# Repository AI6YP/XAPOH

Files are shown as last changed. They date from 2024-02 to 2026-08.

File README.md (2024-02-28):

<p align="right"></p>

# Спутник Плутона -- ХАРОН

Предварительные каскады для Analog Devices ADALM-PLUTO SDR.

https://wiki.analog.com/university/tools/pluto

* Передняя панель управления и индикации
* Задняя панель с разъёмами
* Основная плата

## Панели v1.0.0

### Вид спереди / сзади




Исходные файлы для печатной платы:
* hw/front.svg
* hw/back.svg

Для получения KiCAD проекта используйте Inkscape + svg2shenzhen

https://github.com/badgeek/svg2shenzhen

Для получения GERBER файлов используйте KiCAD

Для надписей использован шрифт B612:

https://fonts.google.com/specimen/B612

### Перечень элементов

| Поз.<br> обозна- <br>чение | Наименование | Кол. | Примечание |
|-|-|-|-|
| D1 | VS1838B | 1 | |
| R1 | Переменный резистор 10К | 1 | |
| ИН1 | Индикатор 2" TFT ST7789V | 1 | |
| SB1 SB2 | Кнопка 6x6x5 | 2 | |
| Р1 - Р9 | SMA -> IPEX | 9 | |
| Р10 | DB9 | 1 | |

### Передняя панель

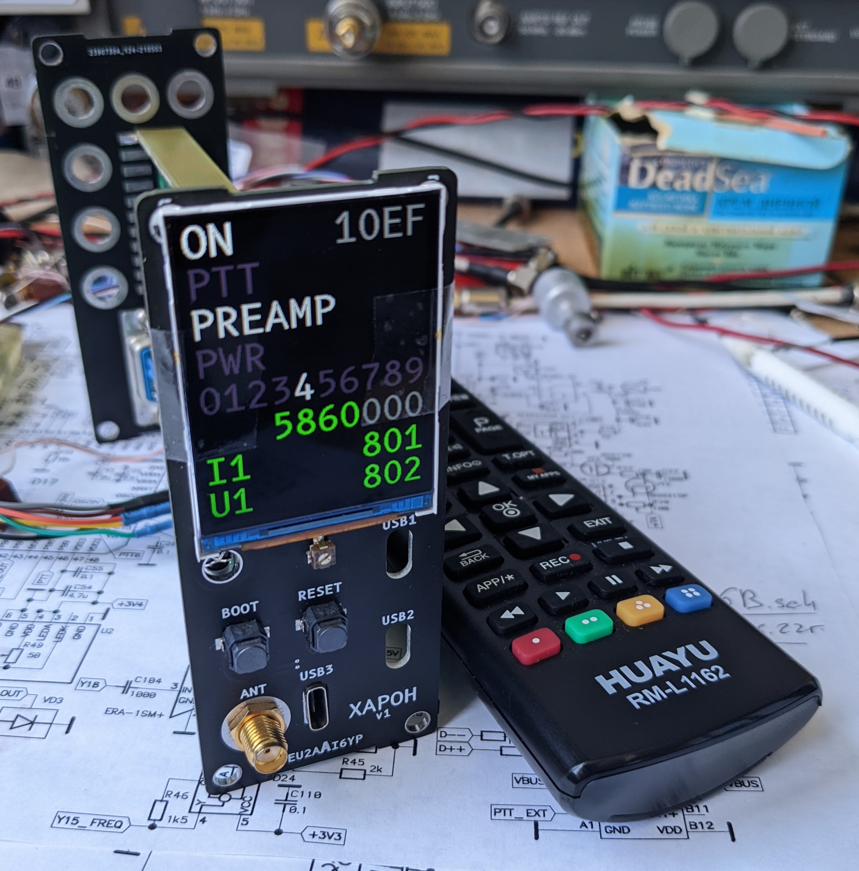
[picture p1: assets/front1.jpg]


### Вид спереди в корпусе

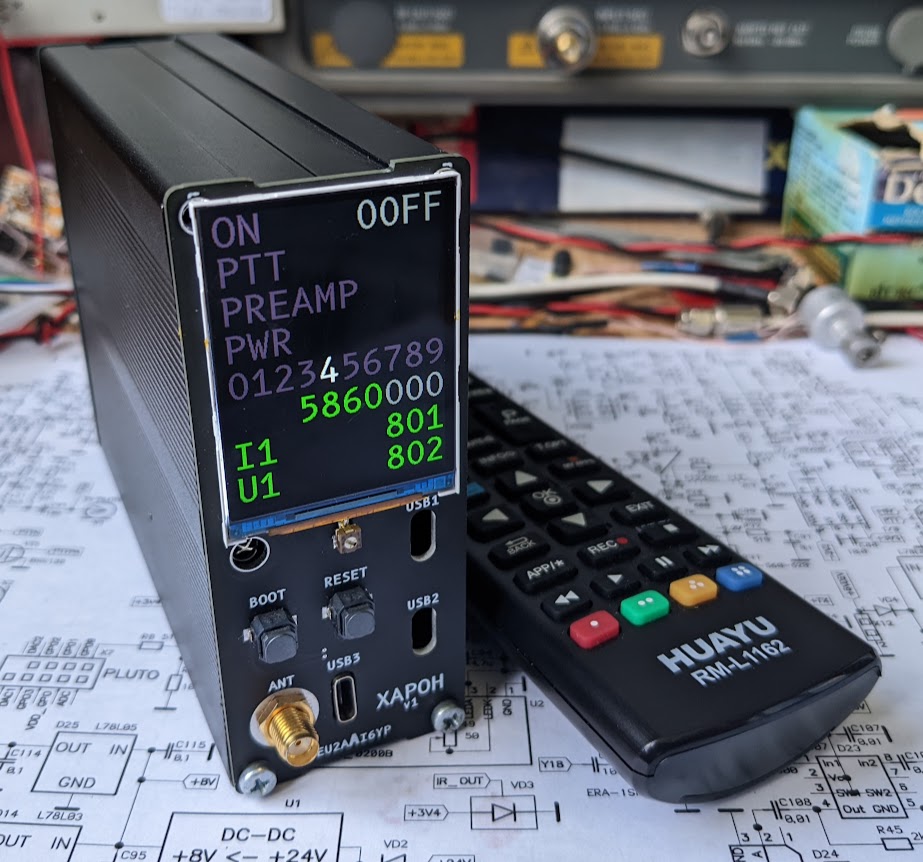
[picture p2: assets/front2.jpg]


### Задняя панель

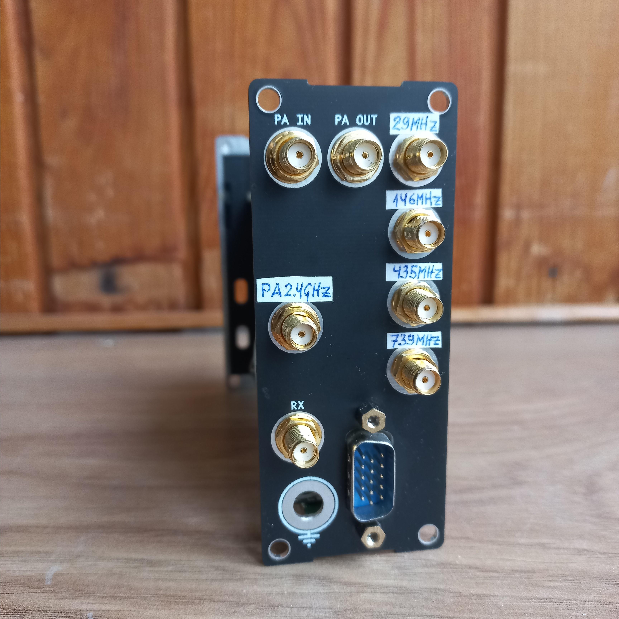
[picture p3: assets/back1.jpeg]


## Основная плата v1.0.0

### Схема антенной секции

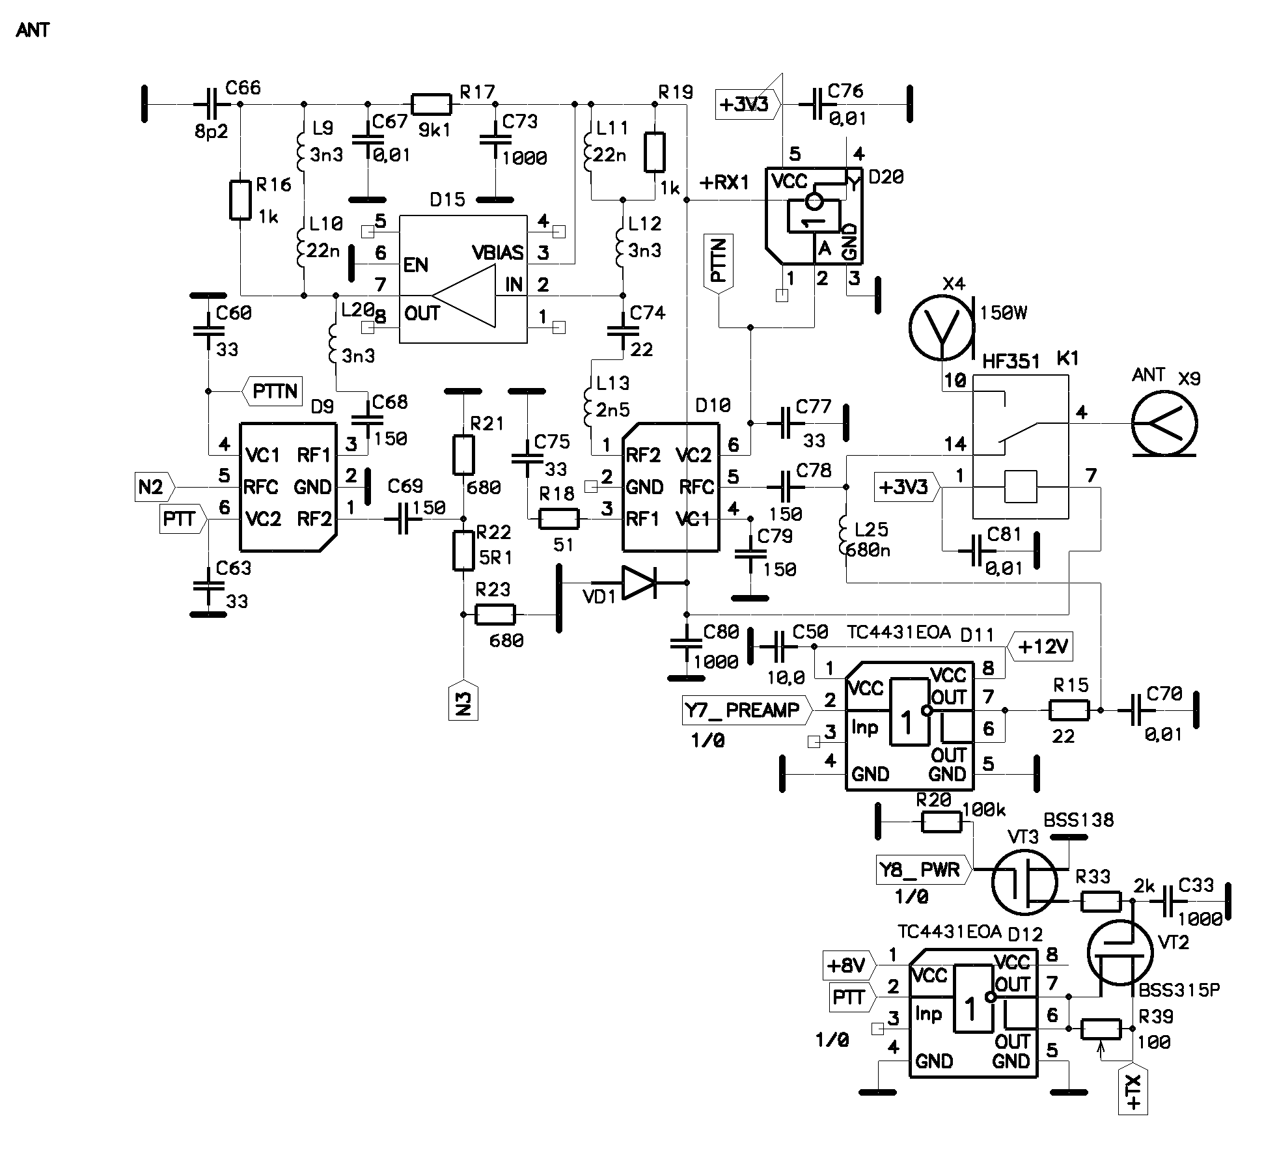
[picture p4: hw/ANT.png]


### Схема процессорной секции

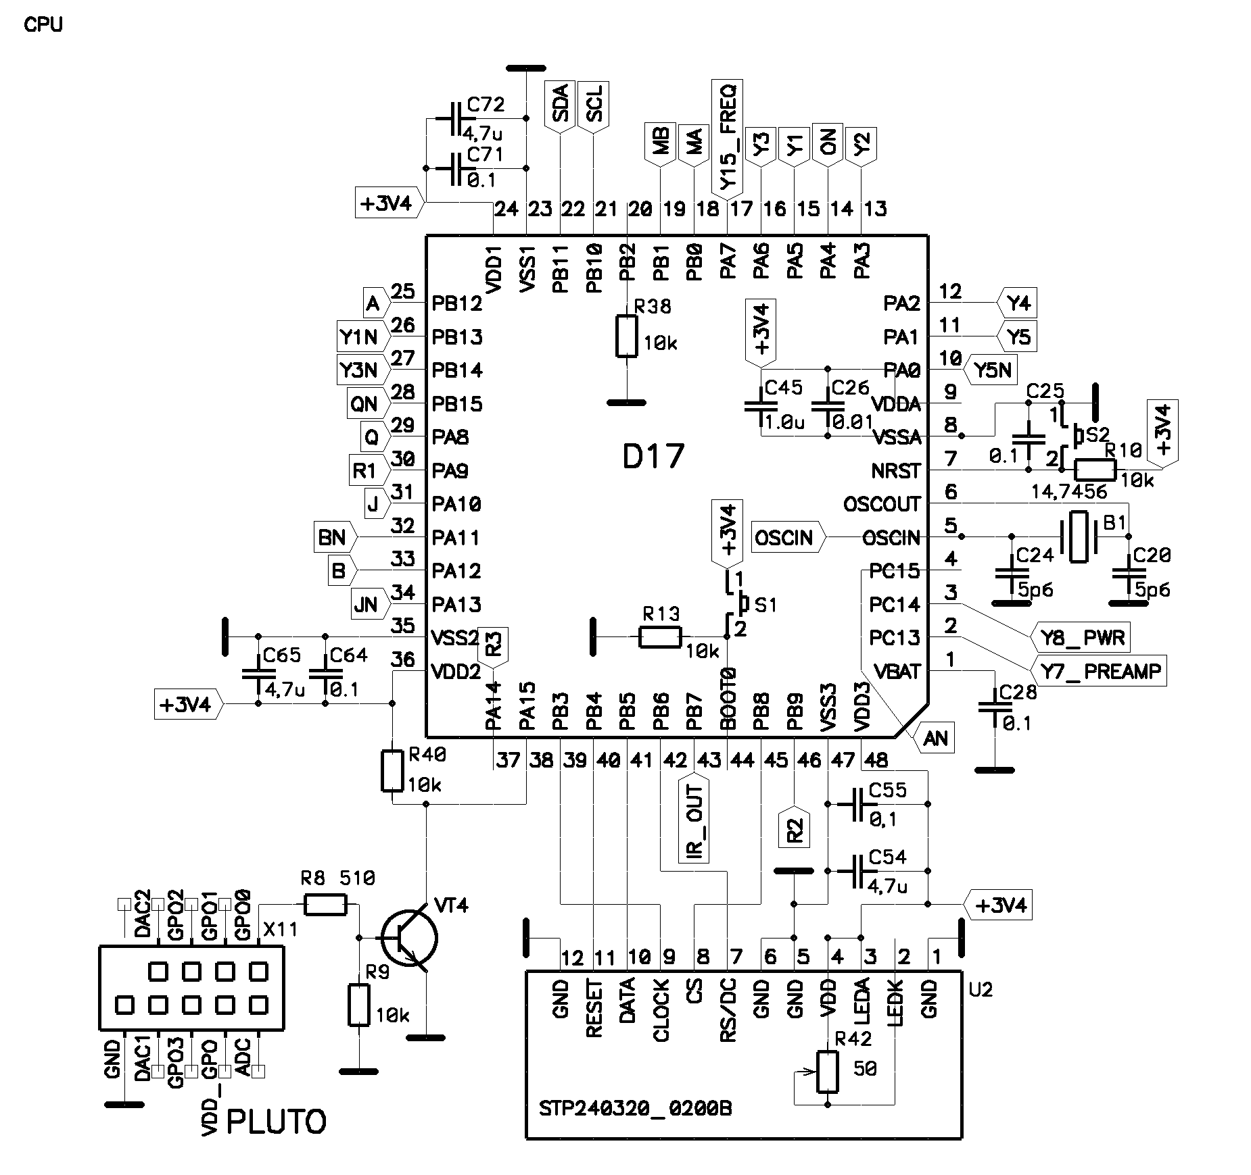
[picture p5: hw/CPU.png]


### Схема секции источник питания

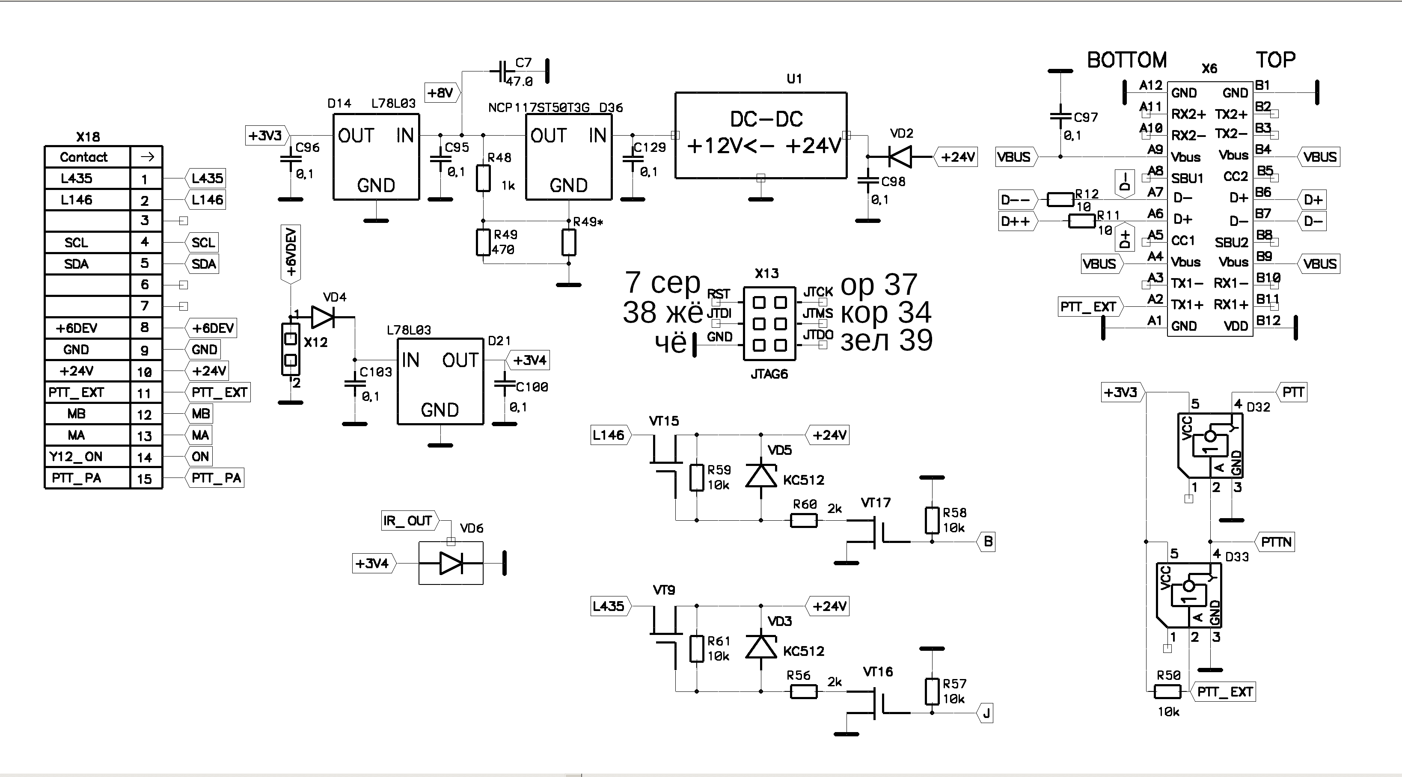
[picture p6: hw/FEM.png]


### Схема секции фильтров

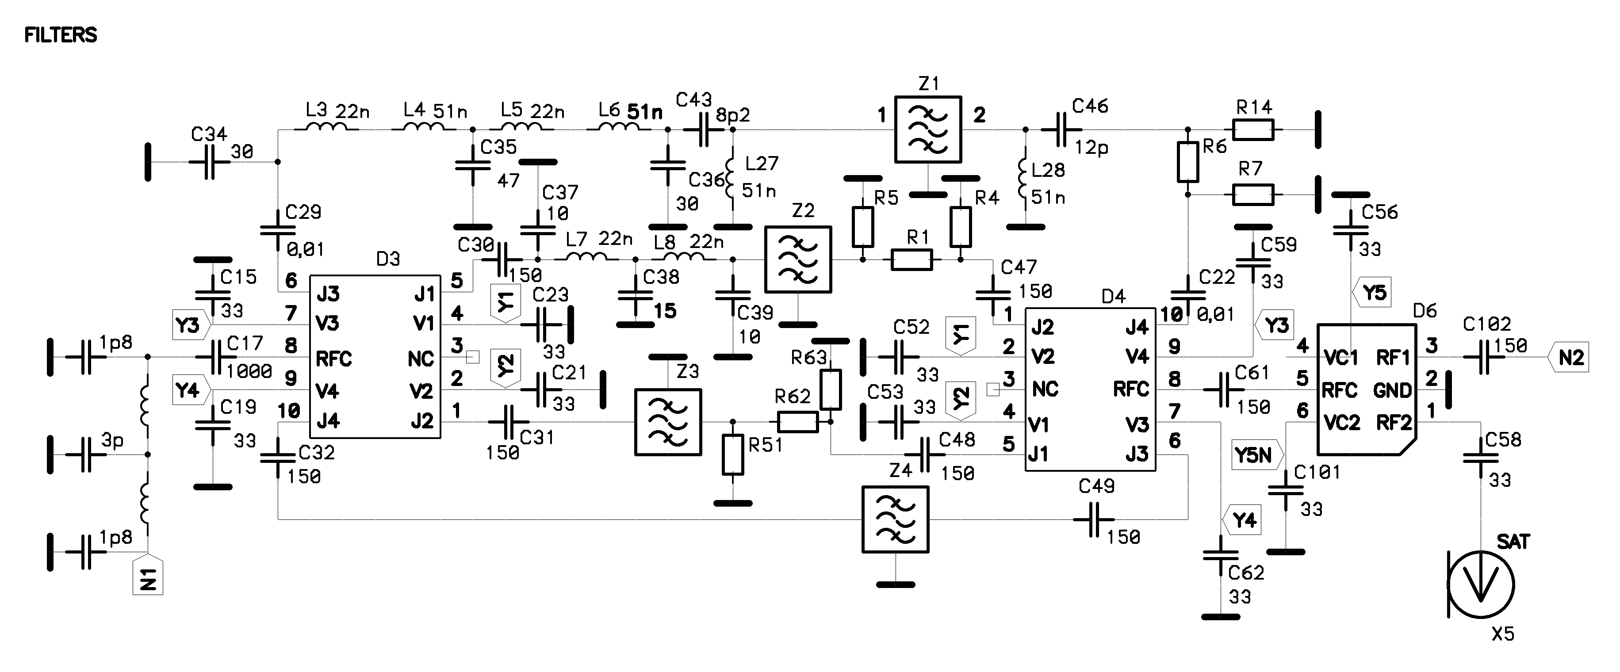
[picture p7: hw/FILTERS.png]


### Схема секции усилителя

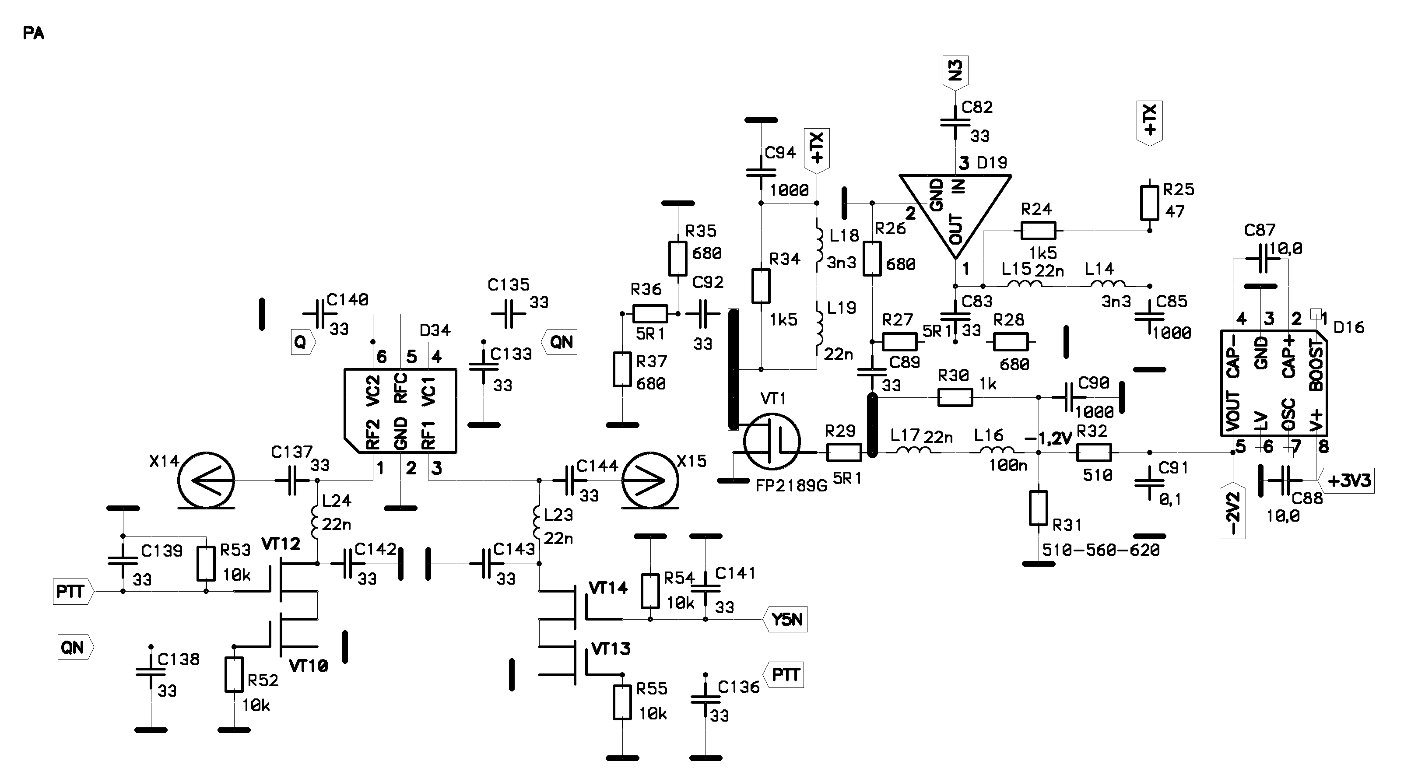
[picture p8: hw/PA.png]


### Схема секции приёмника

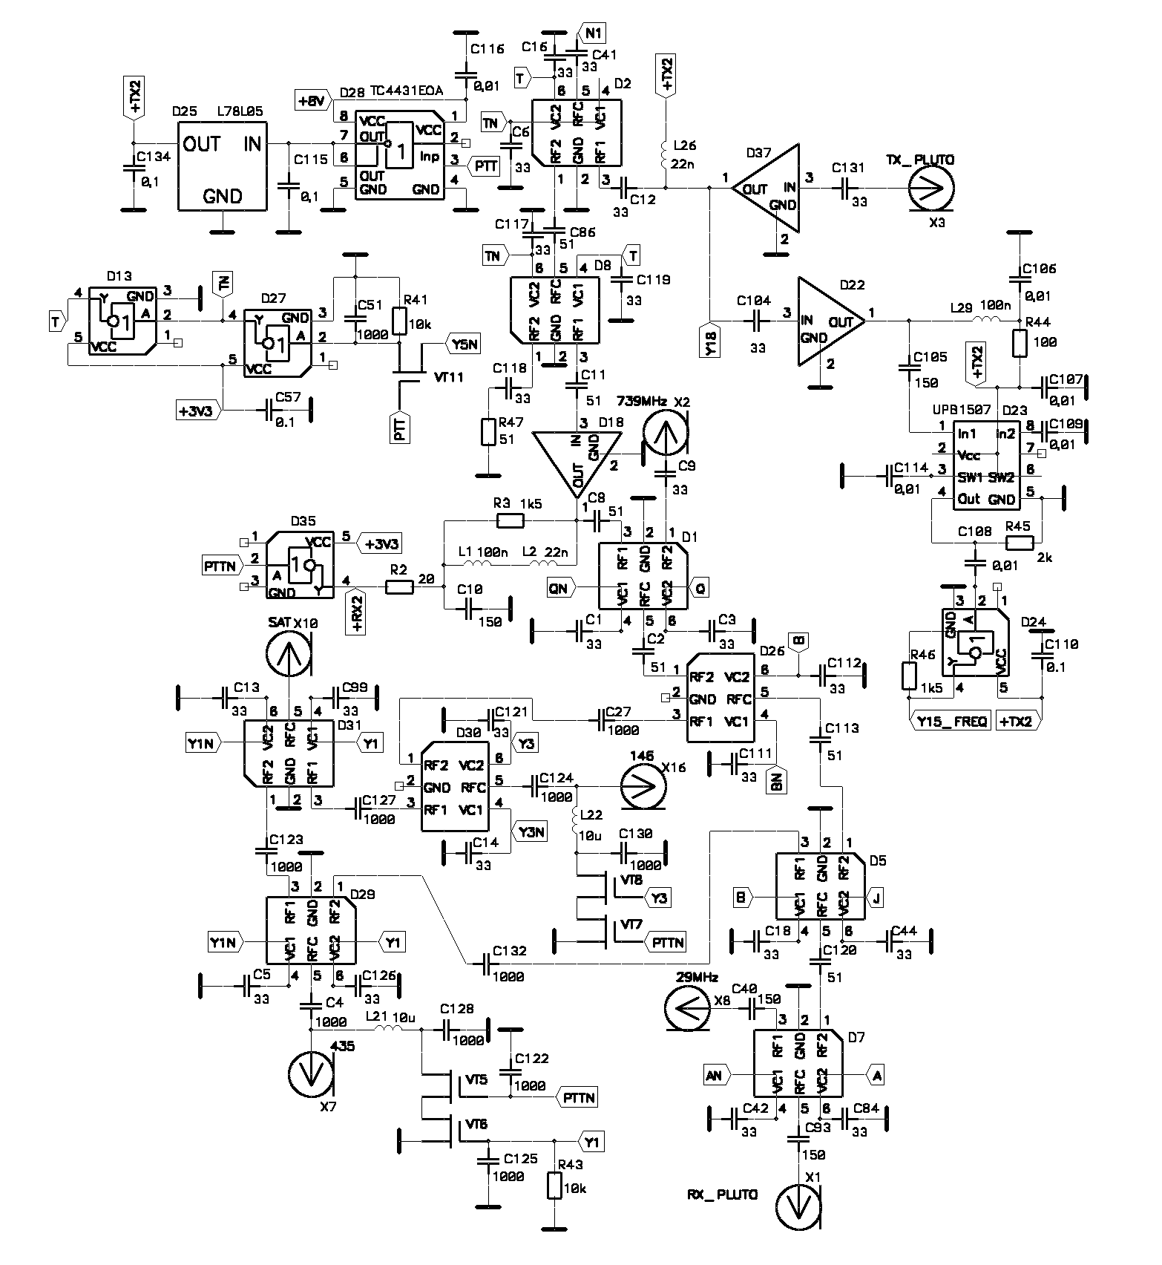
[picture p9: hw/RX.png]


### Топология платы лицевая сторона

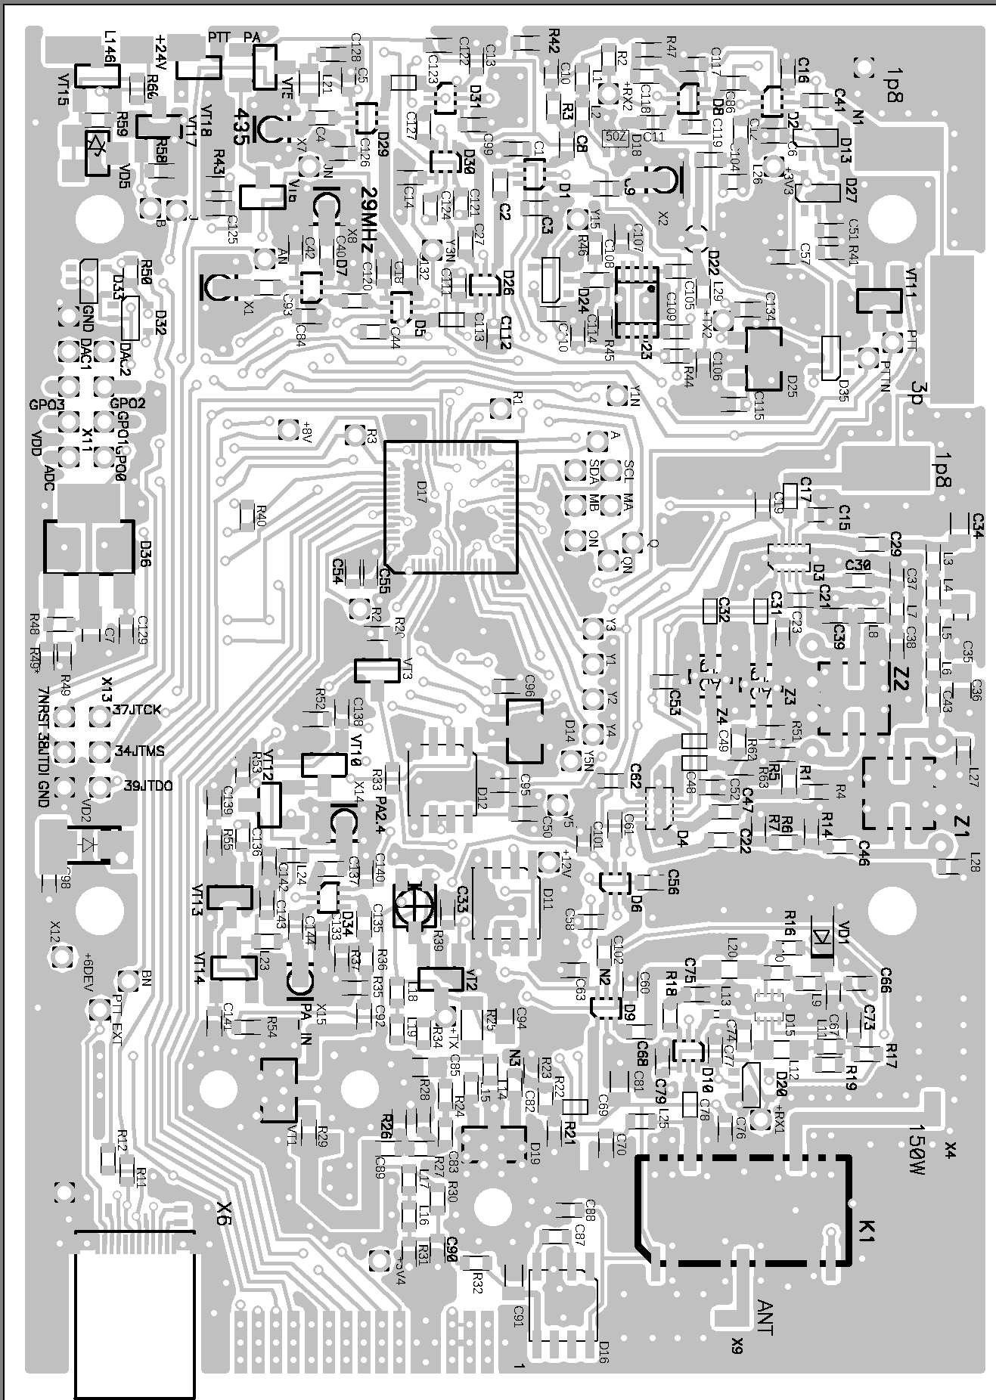
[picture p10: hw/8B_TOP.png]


### Топология платы обратная сторонв

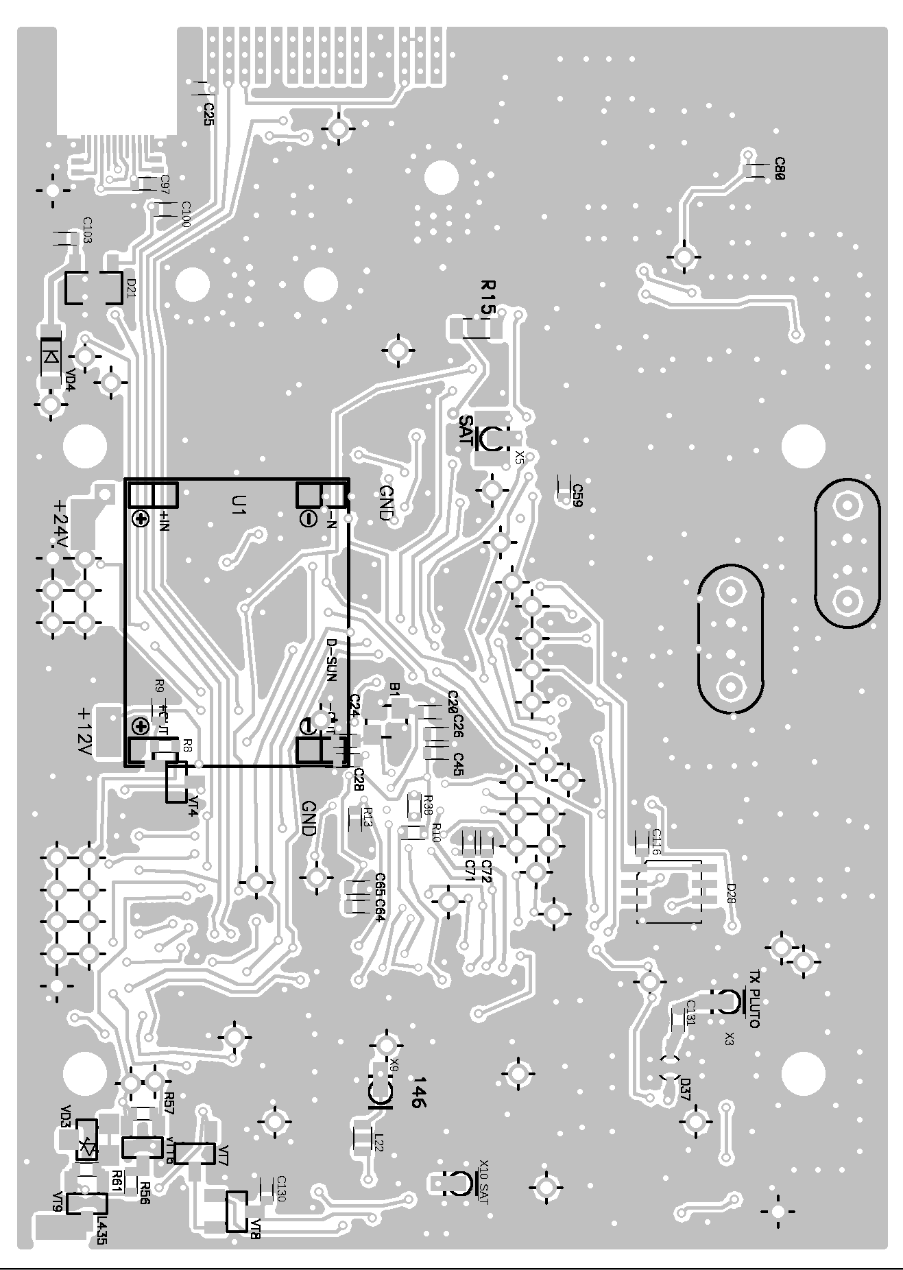
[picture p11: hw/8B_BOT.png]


## Корпус

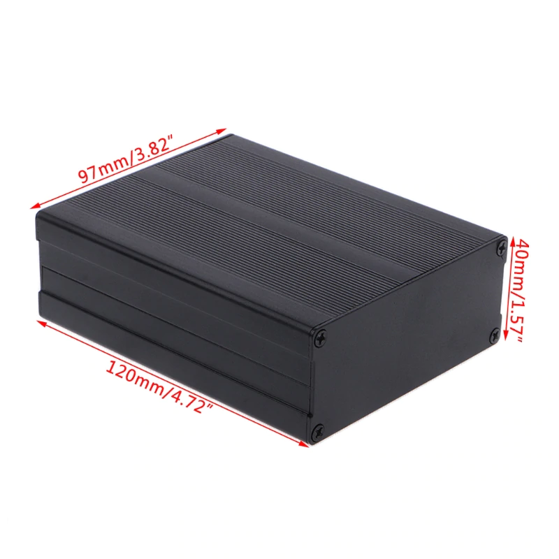
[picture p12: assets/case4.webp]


## Индикатор

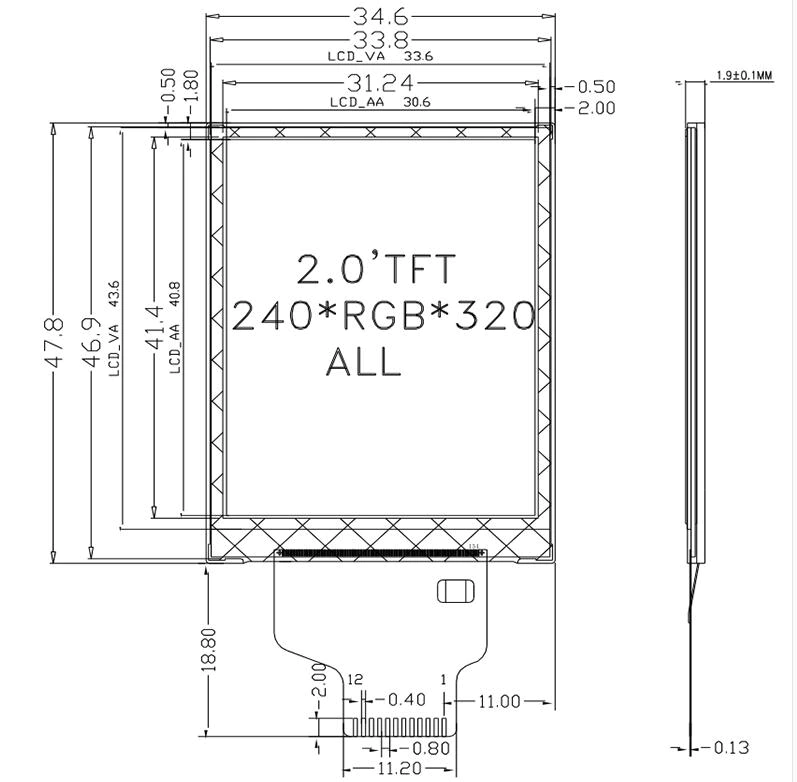
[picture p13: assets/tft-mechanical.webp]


## Фото устройства

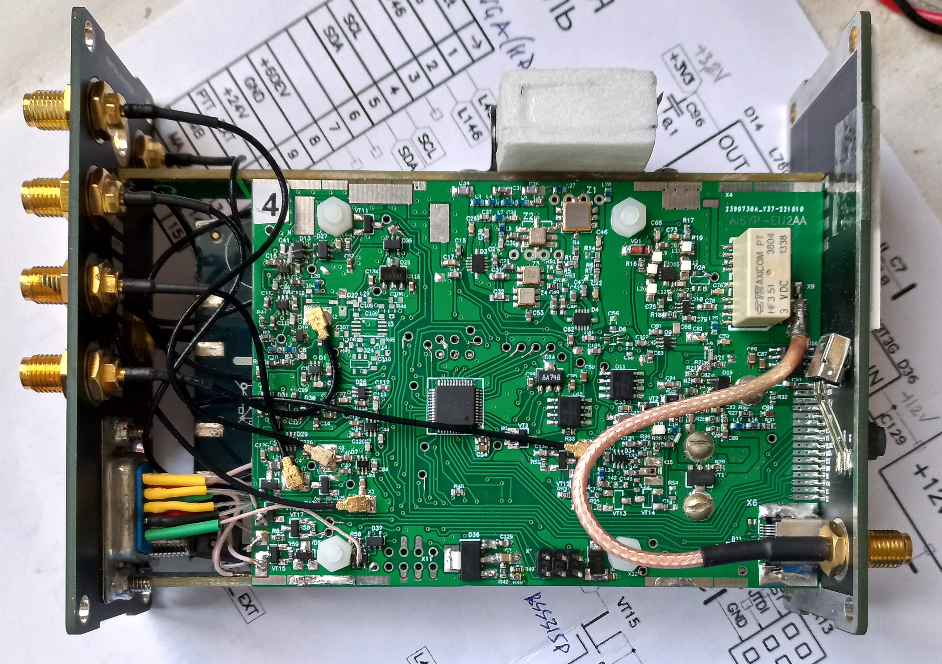
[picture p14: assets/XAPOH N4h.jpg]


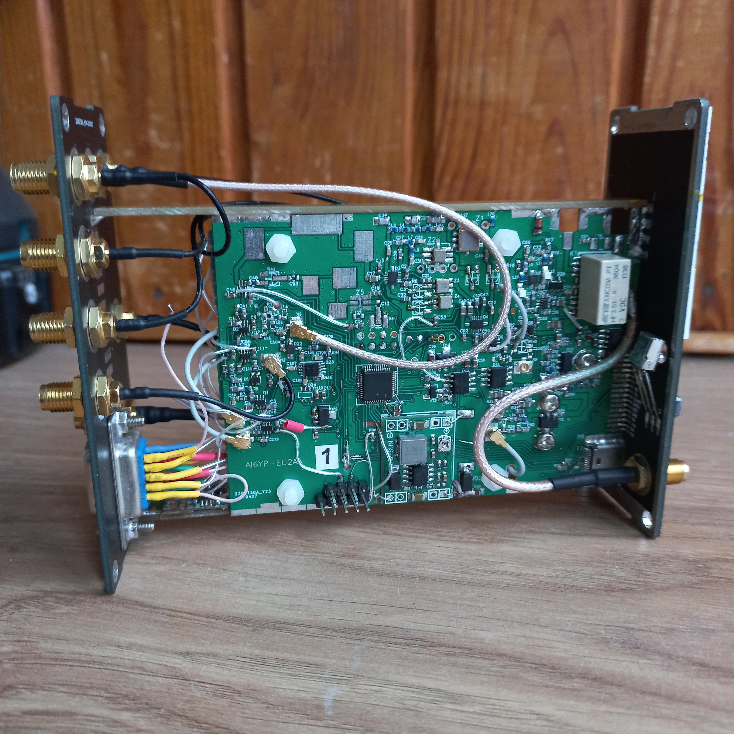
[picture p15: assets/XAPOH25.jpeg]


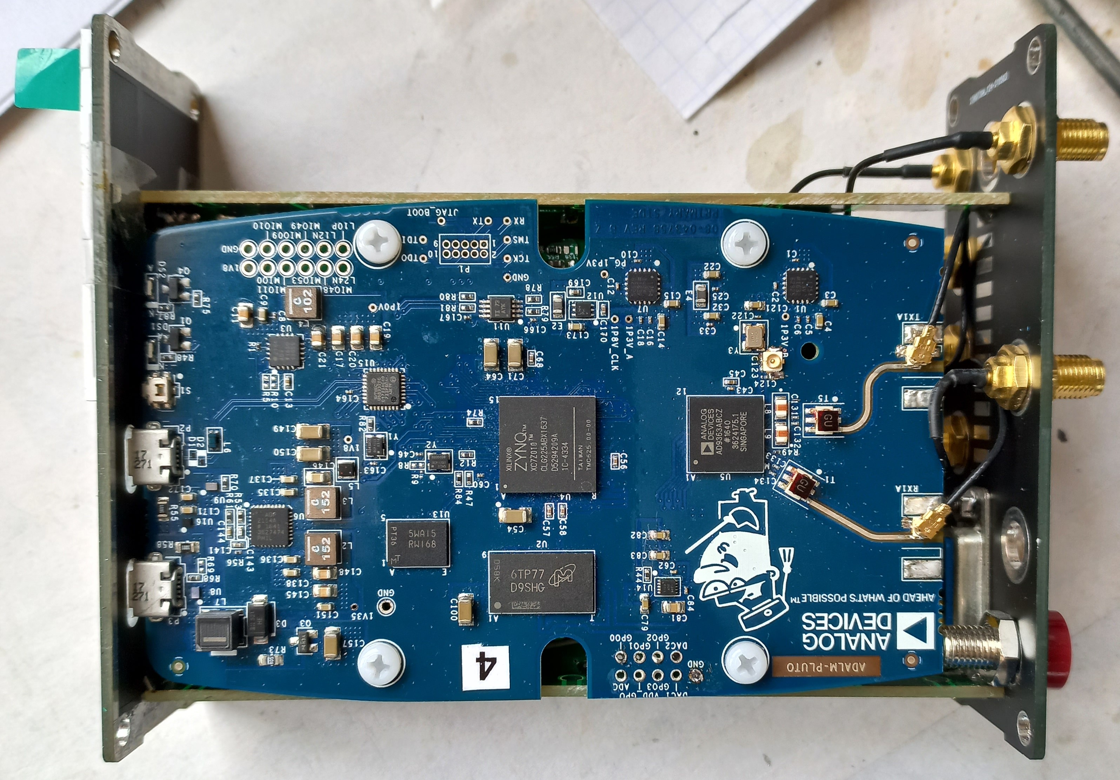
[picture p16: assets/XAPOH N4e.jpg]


## Перечень элементов

hw/8B_PE.doc

## License

Hardware is released under the [CC BY-SA 4.0](https://creativecommons.org/licenses/by-sa/4.0/) license.

Software is relesed under [MIT](LICENSE) license.

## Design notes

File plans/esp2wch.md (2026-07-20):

### What we have now

* main C control software in XAPOH/sw-panel-v3/ folder running on esp32c6 and controlling XAPOH device via 3 I2C port expanders. via HW I2C master interface ports 3,4.
* i2c port expander code in XAPOH/sw-v3/expander running on 3 CH32V003 devices connected by I2C, via ports PC1/PC2 (I2C slave mode) controlled by esp32c6.
* web interface tool web3 with 2 tabs:
  - bridge: programming esp32c6 control software binary image and WiFi configuration.
  - expander: programming port expander device binary images via WCH-LinkE programmer -> PD1/SWIO pin 18.

### What we want to build

* New main C control software in XAPOH/sw-panel-v4/ folder running on esp32c6
* controlling XAPOH device via 3 CH32V003 devices, connected via 3 point-to-point wires from esp32c3 ports 0,1,2 to SWIO port of each of 3 CH32V003 devices.
* esp32c6 will act a CH32V003 programmer via SWIO pin to flash FW similar to ch32fun/minichlink code.
* CH32V003 device software in XAPOH/sw-v4/ will use SWIO pin 18 in UART RX mode to recieve port values from esp32c6.

---

## Architecture & Implementation Plan (v4)

### Decisions locked (2026-06-30)
- Runtime data flow: **TX-only**, ESP32-C6 → CH32V003. CH32 never replies. (matches v3, where `onWrite` only drives outputs)
- CH32V003 core clock: **keep 1.5 MHz** (HSI/16, as v3 `funconfig.h`).
- Session scope: architecture + this written plan. No code yet.
- SWIO programmer source: port cnlohr `esp32s2-cookbook/ch32v003programmer`; fall back to fully in-repo port if cleaner.

### The core idea: one wire, two roles
Each CH32V003 PD1 (chip pin 18) is wired point-to-point to one ESP32-C6 GPIO
(gpio0/1/2). That single wire is time-shared:

1. **Flash time** — ESP32-C6 bit-bangs WCH single-wire RV-SWD (SWIO) on the pin
   to halt the core and program flash, replacing the external WCH-LinkE.
2. **Run time** — ESP32-C6 sends a UART byte stream; the CH32 reads it on the
   same pin via **USART1 RX remapped to PD1**.

Feasibility confirmed: CH32V003 `AFIO->PCFR1` USART1 remap = `01`
(`AFIO_PCFR1_USART1_REMAP` set, `..._REMAP_1` clear) maps **USART1_RX → PD1**
(TX → PD0). See `cnlohr/ch32fun/ch32fun/ch32v003hw.h:1566`.

The pin reuse only works because at run time the CH32 keeps PD1 as an **input**
(USART RX), so it never fights the line, and the QingKe debug module stays alive
(do NOT disable SWD via option bytes), so the ESP can re-enter debug to reflash.

### Operating modes (set by a physical jumper)
The board has **two mutually-exclusive modes, selected by a physical jumper
before power-up** — the ESP does NOT switch them:

| | jumper / power | ESP32-C6 link | host | CH32 flashing | ESP SWIO |
|---|---|---|---|---|---|
| **Program** | 3.3 V–3.3 V | USB → host PC | web4 over USB (WebSerial) | yes, on web4 button | yes |
| **Operation** | 3.3 V–5 V | no USB; WiFi | WiFi WS (hosted UI/app) | never | **never** |

Consequences of the jumper model:
- **No ESP-controlled rail switch** — removed. Mode = physical jumper + power.
  Powering up in Program mode gives the clean 3.3 V state for SWIO.
- **Transport splits by mode.** Program: web4 ↔ ESP over **USB serial**; the
  "flash expander N" command only exists on USB. Operation: panel control over
  **WiFi WS**. So "ESP never performs SWIO in operation" falls out for free — with
  no USB host there is no flash command to act on.
- **Mode detection — none needed (command-driven).** The ESP always boots the
  operational role (WiFi + UART TX). It also listens on USB-serial; a flash command
  from web4 is the *only* thing that starts SWIO. In Operation mode there is no USB
  host, so no command arrives → no SWIO. No boot-time role branch, no strap.
- The "reflash a *running* chip without NRST" risk still applies: in Program mode
  the CH32 powers up and starts its firmware (remaps PD1→USART RX) before the ESP
  halts it. Re-entry relies on the always-on QingKe debug tap (cnlohr does this
  routinely) — still a test item.

### Link-wire levels & pull-up (hardware)

| mode | ESP32-C6 | CH32V003 | link wire |
|---|---|---|---|
| **program (SWIO)** | 3.3 V | **3.3 V** | both 3.3 V — matched, bidir SWIO clean |
| **operation (UART)** | 3.3 V | **5 V** | mismatch: 3.3 V driver → 5 V receiver |

Operation-mode level check — **no level shifter needed.** CH32V003 input-high
threshold is `VIH = 0.22·(Vdd − 2.7) + 1.55`:
- Vdd = 5 V → VIH = **2.06 V**. ESP 3.3 V push-pull high clears it with margin.
- Vdd = 3.3 V (program) → VIH = **1.68 V**. Also fine.

So ESP→CH32 (3.3 V → 5 V) is reliable directly. Direction is one-way (CH32 PD1
stays an input), so the **ESP never sees 5 V** — *provided the link net's pull-up
is referenced to 3.3 V, not 5 V*, and CH32 firmware never drives PD1.

Pull-up (decided): use the **internal pull-up** via the `R_GLITCH_HIGH` technique
from the cookbook SWIO code (no external 10k). Requires setting the gpio drive to
**5 mA** so the brief active-high glitch works. Only used during SWIO (program
mode, both 3.3 V). Operation UART is push-pull, no pull-up needed; the line never
sits at 5 V on the ESP pin.

### v3 → v4 delta
| | v3 | v4 |
|---|---|---|
| ESP↔CH32 transport | HW I2C master (gpio3/4), addr 0x0A/0B/0C | 3× point-to-point single wire (gpio0/1/2) |
| CH32 runtime input | I2C slave on PC1/PC2 | USART1 RX on PD1 (SWIO), 1-way |
| CH32 addressing | PD0 strap → 0xa/0xb/0xc | none — point-to-point, identical FW on all 3 |
| CH32 flashing | external WCH-LinkE on PD1 | ESP32-C6 bit-bangs SWIO on PD1 |
| ESP role | WiFi + WS + I2C + RGB | WiFi + WS + SWIO programmer + 3× UART TX + RGB |
| `i2c_slave.h` | used | dropped |

The web/WS framing (`buf[0]==255` → RGB strip; else → port values) and the
register→GPIO bit mapping (`onWrite` in `sw-v3/expander/main.c`) carry over
unchanged in spirit.

---

### Component A — `sw-v4/` : CH32V003 firmware (UART RX expander)
ch32fun project, Makefile modeled on `sw-v3/expander/Makefile`. `funconfig.h`
keeps 1.5 MHz HSI.

**Low-noise / RF discipline (hard requirement — chip sits inside sensitive RF).**
Goal: minimal spectral emission. Rules:
- **Lowest clock, no PLL.** Keep HSI/16 = 1.5 MHz (`FUNCONF_USE_PLL 0`). Do not
  enable PLL or HSE. 1.5 MHz is the floor that still supports the chosen UART baud
  (19200/9600); don't go lower than the baud needs.
- **Sleep by default.** Core in `__WFI` (or `__WFE`); wake only on USART1 RXNE
  interrupt, process the frame, apply outputs, sleep again. No polling loop, no
  SysTick, no periodic timers.
- **Slow slew on outputs.** Use the **2 MHz** output mode (`GPIO_Speed_2MHz`),
  not v3's 50 MHz — slower edges = far less HF harmonic content.
- **Toggle less.** Only write GPIO pins whose bit actually changed vs last frame
  (diff against shadow copy); never re-drive all 17 each update. No idle blinking.
- **Gate unused clocks.** Enable only GPIO ports in use + USART1 + AFIO; leave
  all other peripheral clocks (I2C, SPI, TIMx, ADC) off.
- **Keep the link static between updates** (see Component C: ESP sends only on
  change, line idle-high). The data wire is the main in-band noise source during
  operation; event-driven traffic minimizes its duty cycle.

- GPIO outputs: **14 active now** (same set as v3):
  PD4,PD5,PD6,PD7,PA1,PA2,PC0,PC3,PC4,PC5,PC6,PC7,PD2,PD3.
- The 3 pins freed by dropping I2C — **PD0** (was addr strap), **PC1**/**PC2**
  (was I2C) — are **reserved as inputs for now** (enable as outputs later as
  needed). Configure as input with a defined pull (avoid floating → RF noise).
- Reserved: **PD1** = SWIO / USART1 RX (the link wire).
- Drop I2C / `i2c_slave.h` / PD0 strap entirely.
- Configure USART1: enable AFIO, set `PCFR1` USART1 remap=01 (RX→PD1), PD1 as
  input-floating/pull-up, USART1 RX-only, RXNE interrupt.
- Baud: **4800** (decided). Clean at 1.5 MHz: USARTDIV 19.5 (eff 4808, +0.16%),
  well within ±2.5%. Only a 5-byte frame ships per change, so speed is irrelevant;
  lower = less noise + bigger SWIO-timing separation. Plenty of core cycles between
  bytes for the trivial ISR.
- State = **3 bytes** (fixed format; 14 bits active now, b2 reserved). Bit map:
  b0[0..6]=PD4,PD5,PD6,PD7,PA1,PA2,PC0; b1[0..6]=PC3,PC4,PC5,PC6,PC7,PD2,PD3
  (both as v3). b2[0..2] reserved for PD0/PC1/PC2 — **ignored** until those pins
  are switched to outputs (keeps the wire protocol stable when they're enabled).
- Framing: **full-state push** (no addressing) — send the whole 3-byte snapshot on
  any change. Frame = `0xAA (sync) | b0 | b1 | b2 | (b0^b1^b2) (checksum)` = 5 bytes.
  ISR collects 5 bytes, validates sync + checksum, then applies the bit→GPIO map
  (diff against shadow, drive only changed pins). Bad frame → resync on next 0xAA.
  Idempotent: a dropped frame self-heals on the next change push.
- Must **not** disable debug (no option-byte SWD-off) so the ESP can reflash.

### UART vs SWIO non-conflict (critical — must not accidentally halt the chip)
The QingKe debug tap on PD1 is **always live** (that is exactly what lets the ESP
reflash a running chip). So UART bytes physically reach the debug FSM. We must
guarantee UART traffic can never be mistaken for a programming transaction.

Why it's safe — two independent margins:
1. **Timing separation (~100×).** SWIO encodes a bit by the *width of the low
   pulse* at ≈1 µs (`t1coeff`): short-low = 1, long-low (4×) = 0; line idles high.
   A UART bit at 9600 is 104 µs (208 µs at 4800). Every UART low is ~100–800× too
   long to read as any valid SWIO bit, so the debug FSM treats it as idle/reset
   noise, never a clocked bit.
2. **Halt needs a complete valid DMI write** — start + 7-bit address + 32-bit
   data + parity at SWIO timing. UART framing physically cannot assemble that. The
   worst pattern (a 0x00 byte ≈ 0.9 ms continuous low = a UART BREAK) only pokes
   the debug-FSM reset; the core keeps running, it does **not** halt.

Design rules that lock this in:
- Keep baud low (9600/4800) — preserve the timing gap; never raise it toward µs.
- The ESP emits **only** UART (104 µs bits, push-pull) in operation and **only**
  SWIO (1 µs pulses) in program mode — never both; mode is interlocked + the rail
  switch power-cycles between them (Power domains).
- Never run the SWIO debug-entry "song and dance" during operation.
- Line idles high in both modes (UART idle = SWIO idle), so transitions out of
  idle are always unambiguous to each receiver.
- Optional belt-and-suspenders: avoid all-zero payload bytes (e.g. keep b2 sync
  bits set, or invert) to eliminate the long-BREAK pattern entirely. Cheap; do it
  if P2 testing shows any FSM disturbance.
- **Verification (P3):** stream worst-case UART (incl. 0x00 floods) at full rate
  to a *running* CH32 and confirm via its outputs that it never halts/resets.

### Component B — `sw-panel-v4/components/swio_programmer/` : SWIO flasher on C6
**Fresh in-repo C port** (decided A10) — no dependency on a cookbook checkout.
Write the bit-bang + DMI/flash layer directly in this component, using cnlohr
`esp32s2-cookbook/ch32v003programmer/main/{bitbang_rvswdio.h,ch32v003_swio.h}` and
`web3/lib/wchlink.js` as references (the latter is the validated DMI/flash oracle).

CH32V003 is **pure single-wire SWIO** (no SWCLK). Reused primitives:
`Send1BitSWIO`/`Send0BitSWIO`/`ReadBitSWIO`, `MCFWriteReg32`/`MCFReadReg32`,
`InitializeSWDSWIO`, `UnlockFlash`, `EraseFlash`, `Write64Block`/`WriteWord`,
`WaitForFlash`/`WaitForDoneOp`. All take `pinmaskD` → call with the gpio mask of
the target being flashed; program the 3 chips sequentially.

Porting work (the real risk):
1. **`PrecDelay` is Xtensa asm** (`addi`/`bbci`). Rewrite as a RISC-V busy loop
   (inline `asm` or `esp_cpu_get_cycle_count()` spin). C6 core = 160 MHz.
2. **Calibrate `t1coeff`** for 160 MHz (S2 was 240 MHz). Verify SWIO bit timing
   on a scope or by successful program+verify.
3. GPIO regs: `GPIO.out_w1ts/w1tc` (drive) and `GPIO.enable_w1ts/w1tc`
   (direction) exist on C6 — confirm field names in C6 `soc/gpio_struct.h`.
4. **Interrupt jitter**: WiFi/FreeRTOS ISRs corrupt cycle-counted timing. Wrap
   timed bit sequences in a critical section (`portENTER_CRITICAL` / disable
   interrupts) at per-word or per-64B-block granularity. Flashing briefly stalls
   WiFi for a few seconds — acceptable; do it in short windows.
5. SWIO needs a pull-up: prefer external 10k on each wire; else enable
   `R_GLITCH_HIGH` + 5 mA drive (internal-pull hack, less reliable).

Cross-check: the DMI register sequence (unlock keys, `CR_PAGE_*`, `DMCONTROL`
halt/reset, progbuf opcodes) is identical to the already-working
`web3/lib/wchlink.js` — use it as a reference oracle while bringing this up.

Reset/reflow without NRST: reset target via debug module `DMCONTROL` ndmreset
(no reset wire exists). Re-entering debug on a running chip relies on PD1 being a
USART-RX input + debug not disabled — **flagged risk, must be tested**.

**Programming-entry sequence (per target).** Runs only in Program mode (jumper
3.3 V–3.3 V, USB host present). The board powered up clean, so no "song and
dance":
1. Set the target gpio to open-drain SWIO with 3.3 V pull-up (it was UART TX).
2. SWIO connect + halt — same DMI sequence as `wchlink.js`
   `connect()/setupDM()/halt()` (DMCFGR/DMSHDWCFGR key, DMCONTROL haltreq). This
   halts the CH32 even though it had already started running its firmware (relies
   on the always-on debug tap — the reflash-running-chip test item).
3. Unlock flash → erase → program → verify (mirror `wchlink.js` `writeImage()`).
4. `DMCONTROL` ndmreset + resume (no NRST wire).
5. Restore the gpio to UART-TX idle-high. (Chip runs the new firmware; full effect
   seen after the next clean power-up in Operation mode.)

### CH32 provisioning model (decided: embedded + explicit-only)
- **One shared CH32 image** (all 3 expanders run identical firmware) is **baked
  into the ESP firmware** — embed `sw-v4/`'s `main.bin` via IDF
  `idf_component_register(... EMBED_FILES ...)` (raw, symbol `_binary_main_bin_start`;
  or a generated header, like
  web3's `EXPANDER_IMAGE`). Single source of truth, ships with ESP OTA.
- **Flash only on explicit command** — in Program mode, a **USB-serial** command
  from web4 ("flash expander N" / all 3) triggers it. **No auto-flash on boot**;
  the ESP never reprograms a CH32 unexpectedly. In Operation mode no USB ⇒ command
  can't arrive ⇒ no SWIO ever.
- web4 does **not** upload the image — it only triggers; the ESP flashes its
  embedded copy **unconditionally** on the button (A13: no version readback, no
  version gate — button = reflash). Transport = **WebSerial** (A11): the C6
  USB-Serial-JTAG enumerates as CDC; web4 opens it and sends a tiny command (e.g.
  `F0`/`F1`/`F2` to flash expander 0/1/2, or `FA` for all).
- The browser never drives bits — SWIO's ~1 µs timing can't survive WS latency;
  the ESP runs the whole programmer loop locally (Component B).

### Component C — `sw-panel-v4/` : ESP32-C6 app + hosted UI

**Two distinct web surfaces — don't conflate:**
- **Hosted UI** (this component): `sw-panel-v4/lib/` (`main.js` + `main.css`),
  bundled into `main/pages.h` and served by the ESP at `/`. This is the runtime
  control panel the device serves over WiFi.
- **Standalone tool** (Component D, `web4/`): the WebSerial/WebUSB programmer page.

**C.1 — firmware** (`sw-panel-v4/main/`). Fork of
`sw-panel-v3/main/sw-panel-v3-main.c`:
- Keep WiFi STA, HTTP/WS server, RGB-strip RMT path (`buf[0]==255`), config
  partition mmap.
- **Remove** all I2C (`i2c_master_*`, `rdwr_i2c`, dev handles).
- Add UART TX to gpio0/1/2. **A8 revised → single HW UART1, GPIO-matrix-switched.**
  Protocol is TX-only, one target per change, so one HW UART covers all 3: per send,
  route `U1TXD_OUT_IDX` to the target gpio via `esp_rom_gpio_connect_out_signal`,
  `uart_write_bytes` the 5-byte frame, park the other two pins as plain GPIO driven
  high (idle). HW FIFO shifts bits → immune to WiFi/FreeRTOS jitter (no critical
  section, unlike bit-bang). See "HW-UART1 TX refactor" below.
  - (superseded) bit-bang software UART on all 3 (`soft_uart.c`) — jitter-prone
    (frame drops on preempt, no re-send); becomes dead code after the refactor.
- Runtime: a non-RGB WS frame → translate to the 5-byte `0xAA|b0|b1|b2|csum`
  full-state frame and send on the addressed target's TX line. Frame[0]/[1] in v3
  selected the device; keep that selection to pick gpio0/1/2.
- **RF discipline (TX side).** Send a frame to a CH32 **only when its value
  changes** (diff against last-sent shadow); never stream/heartbeat. Hold each TX
  line idle-high (static) between frames. This keeps the data wires — the in-band
  noise source — quiet for the RF circuit (pairs with Component A's diff/sleep).
- Flash path (Program mode only): a **USB-serial** command from web4 carries
  **just {target}** (no image — CH32 binary embedded, see provisioning). Handler
  runs the entry sequence + `swio_programmer` against the embedded image on that
  gpio. Explicit-only; in Operation mode there's no USB so it can't fire.
- No boot-time role branch (A2): always boot operational (WiFi + UART TX) and also
  listen on USB-serial. SWIO happens only when a flash command arrives over USB —
  impossible in Operation mode (no USB host).
- Per-flash gpio interlock: switch the target gpio UART-TX → SWIO before flashing,
  back to UART-TX idle-high after.

**C.1a — HW-UART1 TX refactor (replaces `soft_uart.c`).** Sketch:

- Install once at boot: `uart_driver_install(UART_NUM_1, ...)` +
  `uart_param_config(UART_NUM_1, {baud=4800, 8N1})`. Do **not** call `uart_set_pin`
  (that pins TXD permanently); drive the matrix by hand instead.
- Park all 3 links idle-high as plain GPIO outputs at boot (as `suart_init` does now).
- Per frame to target `idx`:
  ```c
  static int cur = -1;               // gpio currently bound to U1TXD (-1 = none)
  static portMUX_TYPE link_mux = portMUX_INITIALIZER_UNLOCKED;
  void link_send(int idx, const uint8_t *f, size_t n) {
    portENTER_CRITICAL(&link_mux);   // serialize vs flash task + other sends
    int g = link_gpio[idx];
    if (cur != g) {
      if (cur >= 0) {                // park previous pin: plain GPIO, idle-high
        esp_rom_gpio_connect_out_signal(cur, SIG_GPIO_OUT_IDX, false, false);
        gpio_set_level(cur, 1);
      }
      esp_rom_gpio_connect_out_signal(g, U1TXD_OUT_IDX, false, false); // idle=high, no glitch
      cur = g;
    }
    portEXIT_CRITICAL(&link_mux);
    uart_write_bytes(UART_NUM_1, f, n);
    uart_wait_tx_done(UART_NUM_1, pdMS_TO_TICKS(50));
  }
  ```
- No per-bit critical section needed — HW shifter is jitter-proof (fixes F1).
- Interlock with flashing (fixes F3): before `swio_flash_image(g,…)`, if `cur==g`
  detach U1TXD (`SIG_GPIO_OUT_IDX`) so SWIO owns the pin; set `cur=-1`. `suart`/park
  restore after flash re-binds on the next `link_send`. Guard the whole flash under
  `link_mux` (or a higher-level flag) so a WS send can't drive the pin mid-flash.
- `U1TXD_OUT_IDX` / `SIG_GPIO_OUT_IDX` from `soc/uart_periph.h` / `soc/gpio_sig_map.h`.
- Delete `soft_uart.{c,h}` + its `SRCS` entry once `link_send` lands.

**C.2 — hosted UI** (`sw-panel-v4/lib/` + build → `main/pages.h`). Fork
`sw-panel-v3/lib/{main.js,main.css}`:
- Update the control surface for the v4 expander: **14 outputs** per
  panel, 3 panels; keep the RGB-strip control. (PD0/PC1/PC2 stay reserved inputs,
  A7 — b2 ignored; enable later for 17.) WS messages map to the firmware's
  full-state push (per-target 3-byte snapshot) + RGB path (`buf[0]==255`).
- Keep `document.XAPOH_VERSION` injection from `manifest.json`.
- Uses `onml` for DOM (as v3); no framework.

**C.3 — build flow: browserify → esbuild.** Rewrite `sw-panel-v3/page-to-h.js`
as `sw-panel-v4/page-to-h.js` using **esbuild** instead of browserify:
- `esbuild.build({entryPoints:['lib/main.js'], bundle:true, minify:true, write:false})`
  → take `outputFiles[0].text` as the script string (replaces the
  `browserify().bundle()` promise).
- Same downstream: wrap script+css in the HTML template, write `lib/index.html`,
  emit `main/pages.h` (`PAGE_index` byte array + `PAGE_index_length`, `DRAM_ATTR`).
- `package.json`: drop `browserify`, add `esbuild`; keep `onml`, `eslint`.
  (web3/web4 already build with esbuild via `web*/bin/build.js` — this aligns the
  hosted-UI build to the same toolchain.)

### Component D — `web4/` : standalone programmer tool (later)
The standalone WebSerial/WebUSB tool (NOT the device-hosted UI — that's C.2).
New folder `web4/` (do NOT modify `web3/`). Fork the `web3/` build
(esbuild → single `index.html`, `lib/` modules) as the starting point — web3 is
already on esbuild, so the toolchain carries over directly.

Current `web3/lib/wchlink.js` flashes CH32 via WebUSB WCH-LinkE. web4 instead
sends a **"flash expander N" trigger over WebSerial** (A11) — the ESP flashes its
*embedded* CH32 image via SWIO (Component B), so web4 carries no CH32 binary and
the WebUSB WCH-LinkE dependency is retired. Button = unconditional reflash, no
version readback (A13). ESP bridge flashing (esptool over WebSerial) unchanged.
web4 is the USB programmer tool **only** — no operational panel control (A12);
that lives in the WiFi hosted UI (C.2).

---

### Phasing
- **P0** Hardware: confirm gpio0/1/2 ↔ PD1 wiring; internal pull-up via
  `R_GLITCH_HIGH` + 5 mA drive (no external 10k); jumper switches CH32 VDD only;
  operation powered externally (no USB). (No level shifter — VIH@5V = 2.06 V; no
  mode strap — command-driven.) Confirm C6 GPIO struct field names.
- **P1** `sw-v4/` CH32 firmware: USART1 RX on PD1 + frame parser + 14-output GPIO
  map (PD0/PC1/PC2 as reserved inputs). Bench-test by driving the wire from a
  USB-serial adapter at 4800.
- **P2** `swio_programmer` component standalone: port bitbang, write RISC-V
  `PrecDelay`, calibrate `t1coeff`, flash one CH32 on gpio0, program+verify
  against a known image (oracle = wchlink.js result).
- **P3** `sw-panel-v4/` skeleton from v3 minus I2C; add 3× UART TX; end-to-end
  runtime control of all 3 panels over WiFi WS. Port the hosted UI (C.2): fork
  `lib/{main.js,main.css}`, rewrite `page-to-h.js` browserify→esbuild, regen
  `pages.h` for the 14-output surface. Run the UART-vs-SWIO non-conflict test.
- **P4** Embed `sw-v4` image into the ESP build (`EMBED_BINARIES`); WebSerial
  `F0/F1/F2/FA` command handler + entry sequence + per-flash gpio interlock; flash
  all 3 from a web4 button. Explicit-only, unconditional reflash, no auto-flash.
- **P5** `web4/` new UI: fork from web3, send the flash trigger to the ESP over USB
  (ESP flashes its embedded image via SWIO); retire WebUSB WCH-LinkE path. ESP
  bridge flashing (WebSerial/esptool) unchanged.

### Decisions (resolved)
- A1 Pull-up: **internal** `R_GLITCH_HIGH` + 5 mA drive (no external 10k).
- A2 Mode: **command-driven** — no strap/role-branch; USB flash command = only SWIO trigger.
- A3 Jumper: switches **only CH32 VDD** (3.3↔5 V).
- A4 Operation power: **external** source; no USB.
- A5 gpio0/1/2: **free** on the board (may relocate if an internal conflict shows up).
- A6 Baud: **4800**.
- A7 Outputs: **14 active now**; PD0/PC1/PC2 reserved as **inputs** (enable later).
- A8 3× TX: **REVISED → single HW UART1, GPIO-matrix-switched** (was bit-bang all 3).
  TX-only + one-target-per-change ⇒ one HW UART; FIFO removes bit-bang jitter.
- A9 All-zero-byte framing mitigation: **skip for now**.
- A10 SWIO programmer: **fresh in-repo port** (cookbook + wchlink.js as references).
- A11 web4↔ESP: **WebSerial** (C6 USB-Serial-JTAG CDC), tiny `F0/F1/F2/FA` command.
- A12 No overlap: web4 = USB programmer only; panel control = WiFi hosted UI.
- A13 No FW-version readback; web4 button = **unconditional reflash**.

### Open risks / to verify
1. RISC-V `PrecDelay` port + SWIO timing calibration at 160 MHz.
2. WiFi ISR jitter vs bit-banged SWIO — critical-section windowing.
3. Reflash a *running* CH32 with no NRST wire — in Program mode the chip powers up
   and runs before the ESP halts it; re-entry relies on the always-on debug tap.
   Clean power-on (jumper at 3.3/3.3) helps, but **must be bench-tested** (P2).
4. Level mismatch — RESOLVED: VIH@5V = 2.06 V < 3.3 V, no shifter. Only constraint:
   keep the link pull-up referenced to 3.3 V so the ESP pin never sees 5 V.
5. UART must never look like a SWIO debug transaction — mitigated by ~100× timing
   separation + "halt needs a full valid DMI write"; verify in P3 (see UART vs
   SWIO non-conflict). Keep baud low; optionally avoid all-zero payload bytes.
6. USART RX reliability at 1.5 MHz core (baud error + ISR latency) — 4800 = +0.16%, safe.
7. UART framing/resync robustness (no addressing, no ACK on a 1-way link).

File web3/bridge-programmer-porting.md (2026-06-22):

# Finish ESP32-C6 bridge programmer in web3

## Context

The ESP32-C6 ("Мост"/bridge) programmer is being migrated from the old Observable
app (`src/components/esp-install.js`) into the standalone `web3/` build
(`web3/lib/main.js` + esbuild → single `index.html`). The CH32V003 expander side
(`web3/lib/wchlink.js`) is already complete. The bridge side is only half-ported:
it connects to the chip but cannot flash. Goal: embed the ESP32 firmware binaries
into the build (like the existing `EXPANDER_IMAGE`) and make the bridge flash all
partitions exactly as `esp-install.js` did.

Two existing bugs block the current bridge path (found in review):
- `web3/lib/main.js:16` uses `xterm.callbacks`, but `xterm` is a factory
  function (`web3/lib/xterm.js:5`), so `.callbacks` is `undefined`.
- `esptool-js` is imported but missing from `web3/package.json` deps.

## Approach

Partition table is generated **at runtime** in the browser (port `t2pt` + `js-md5`),
matching `esp-install.js`. Erase is **per-region** (`eraseAll: false`).

### 1. `web3/package.json` — deps
Add to `devDependencies` (esbuild bundles them):
- `esptool-js` (already imported, currently missing)
- `js-md5` (needed by `t2pt`)

### 2. `web3/lib/esp-partition.js` — NEW (ported helpers)
Port from `src/components/`, browser-import style (no `npm:` prefix):
- `t2pt` — verbatim from `src/components/t2pt.js`.
- `partTable` — the 4-entry table from `esp-install.js:70` (nvs, phy_init,
  factory, **config@0x110000**).
- `cfg2ui8(cfg)` — from `esp-install.js:79`, but read **nested** config:
  `cfg?.wifi?.ssid` / `cfg?.wifi?.password` (editor emits `{wifi:{ssid,password}}`,
  see `web3/lib/mount-bridge-config-editor.js:1`). ssid→offset 0, password→offset 32.
- `ui8ToBstr` helper (binary string for esptool `data`).

### 3. `web3/bin/build.js` — embed bridge bins (bin2js functionality)
Mirror the existing `getExpanderImage` pattern. Read from `../sw-panel-v3/build/`
(authoritative paths in `flasher_args.json`):
- `bootloader/bootloader.bin` → address `0x0`
- `sw-panel-v3.bin` → address `0x10000`

Emit a `BRIDGE_BINS` array of `{name, address, data: <base64>}` and inject into the
HTML template next to `window.EXPANDER_IMAGE`:
```js
<script>window.BRIDGE_BINS = ${JSON.stringify(bridgeBins)};</script>
```
(Do NOT embed IDF's `partition_table/partition-table.bin` — it lacks the config
partition; the table is built at runtime instead.)

### 4. `web3/lib/main.js` — `genOnClickActivateBridge`
- Fix xterm: `const term = xterm();` once; use `term.callbacks` for
  `flashOptions.terminal` (line 16) and `term.div` for the console (line 43).
- Keep `{port, transport, esploader, chip}` from connect; render panel + config
  editor + flash button (existing markup). Fix double-`v` in button label
  (`bridge-fw-${pkgVersion}`).
- Wire flash button handler (replace commented lines 42–43). On click, build
  `fileArray` like `esp-install.js:97` `onProgramClick`:
  1. partition table: `{address: 0x8000, data: ui8ToBstr(await t2pt(partTable, (v)=>new Uint8Array(md5.arrayBuffer(v))))}`
  2. firmware: `window.BRIDGE_BINS.map(e => ({address: e.address, data: atob(e.data)}))`
  3. config: `{address: 0x110000, data: ui8ToBstr(cfg2ui8(cfg))}` — `cfg` parsed
     from the editor's localStorage `bridgeConfig` JSON.
  Then `esploader.writeFlash({fileArray, flashSize:'keep', eraseAll:false, compress:true, reportProgress})`,
  `await esploader.after()`, append `term.div` to `#console`, run the
  `transport.rawRead()` → `term.write(value)` console loop (from
  `esp-install.js:130`).
- `reportProgress(fileIndex, written, total)` → write progress line into the panel.

## Verification
- `cd web3 && npm install` (pulls esptool-js, js-md5).
- `cd web3 && npm run build` → regenerates `index.html`; confirm `window.BRIDGE_BINS`
  present with 2 entries (bootloader@0x0, app@0x10000) and base64 data.
- `cd web3 && npm test` (eslint bin + lib) passes.
- Manual (Chrome, WebSerial): open `index.html`, "Мост" tab → Активировать →
  chip info shows → edit wifi config → flash button → progress for all 3 regions →
  device reboots → console shows ESP32 boot log.

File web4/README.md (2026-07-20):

# web4 — XAPOH programmer tool

Standalone browser tool with two tabs:

- **Мост (bridge)** — flash the ESP32-C6 firmware over WebSerial (esptool-js),
  edit the WiFi config, and open a serial console. Same flow as the web3 bridge tab.
- **Экспандеры** — program the 3 CH32V003 expanders. web4 does **not** drive SWIO:
  it sends a 2-byte trigger (`F0`/`F1`/`F2`/`FA`) over WebSerial and the ESP flashes
  its **compiled-in** CH32 image via SWIO on gpio0/1/2 (see `flash_cmd_task` in
  `sw-panel-v4/main/sw-panel-v4-main.c`).

Program mode only (board jumper 3.3 V–3.3 V, ESP on USB).

## Build
One script builds the whole chain and emits a self-contained `web4/index.html`:

```bash
cd web4
npm install
IDF_PATH=/path/to/esp-idf npm run build      # or export IDF_PATH first
```

`bin/build.js` runs, in order:
1. `make -C ../sw-v4 build` — CH32V003 firmware → `sw-v4/main.bin` (compile only).
2. `node bin-to-h.js` in `../sw-panel-v4` — `sw-v4/main.bin` → `main/expander_image.h`
   (the CH32 image compiled into the ESP app).
3. `node page-to-h.js` in `../sw-panel-v4` — hosted UI → `main/pages.h`.
4. `idf.py build` in `../sw-panel-v4` (sources `$IDF_PATH/export.sh`) — ESP app.
5. `sw-panel-v4/build/{bootloader.bin, sw-panel-v4.bin}` → base64 `window.BRIDGE_BINS`.
6. esbuild-bundle `lib/main.js` → `web4/index.html`.

`npm run watch` rebuilds on changes to `lib/`, `sw-v4/main.c`, `sw-panel-v4/lib/`.

### Prerequisites
- **CH32 build**: the cnlohr `ch32fun` toolchain (riscv gcc) — `sw-v4/Makefile`
  includes `../../../../cnlohr/ch32fun/ch32fun/ch32fun.mk`.
- **ESP build**: a working ESP-IDF at `$IDF_PATH` (fallback path hard-coded in
  `bin/build.js`).

### Partition-table note
`bin/build.js` embeds only the bootloader (`0x0`) and app (`0x10000`). The partition
table (`0x8000`) is built **in-browser** by `lib/esp-partition.js` (`t2pt`) because the
firmware needs a `config` data partition (@`0x110000`) that the default IDF singleapp
table lacks. Do not embed the IDF-built `partition-table.bin` — it would omit `config`
and the firmware would assert at boot.

## Use
Serve over http (WebSerial needs https or localhost):

```bash
cd web4 && python3 -m http.server 8000
# open http://localhost:8000 in Chrome/Edge
```

1. **Мост** → Активировать Мост → pick the ESP USB-Serial-JTAG port → edit config →
   Прошить → progress + console.
2. **Экспандеры** → Активировать → pick the port → `Экспандер 0/1/2` or `Все три`
   sends `F0/F1/F2/FA`; the ESP logs SWIO progress back over serial.

## Protocol
2-byte ASCII command: `'F'` then `'0'|'1'|'2'|'A'`. Handled by `flash_cmd_task`
in `sw-panel-v4/main/sw-panel-v4-main.c`.

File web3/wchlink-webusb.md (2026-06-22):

# WCH-LinkE WebUSB flasher — architecture & plan

> **STATUS: implemented and working on hardware** (WCH-LinkE v2.12 + CH32V003).
> `lib/wchlink.js` flashes `window.EXPANDER_IMAGE` end-to-end from `lib/main.js`:
> connect → `programmerInfo` → `chipInfo` → `nrstAsGpio` (unlock+erase) →
> `writeImage` (write + readback verify) → reboot. All milestones 1-6 done;
> only the optional speed work (milestone 7) remains. This doc is kept as the
> reference for *why* the code does what it does.

Goal: a browser-only JS library (`web3/lib/wchlink.js`) that flashes a `.bin`
into a **CH32V003** through a **WCH-LinkE** programmer over **WebUSB**, with no
native helper. Port of the relevant slice of
`ch32fun/minichlink/` (C + libusb) to `navigator.usb`.

Scope is intentionally narrow:

- Programmer: WCH-LinkE in **RISC-V mode** only — `{vendorId: 0x1a86, productId: 0x8010}`.
- Target: **CH32V003** only (the family minichlink calls `CHIP_CH32V003`).
- Operation: **set NRST as GPIO** (also unlocks + mass-erases) + erase + write
  + verify + reboot. No GDB, no terminal, no general option-byte editing, no
  read-protection toggling, no ARM/IAP-mode recovery in v1.

---

## 1. How minichlink is layered (and what we actually need)

`minichlink` splits into a thin **programmer driver** and a fat **generic
algorithm layer**. The driver only has to provide three primitives; everything
else (chip detect, flash unlock, erase, page write) is built on top of them.

| C layer | File | What it does | Port? |
|---|---|---|---|
| Programmer driver | `pgm-wch-linke.c` | USB transfers, DMI reg read/write, power, setup | **yes (the USB part)** |
| Generic algorithm | `minichlink.c` `Default*` fns | chip detect, flash unlock/erase/write via Debug Module | **yes (reimplement in JS)** |
| Chip table | `chips.c` | per-chip sizes/speed | inline the CH32V003 row |

Critical detail: in `pgm-wch-linke.c`, `FORCE_EXTERNAL_CHIP_DETECTION 1`. So the
LinkE driver installs **only**:

```
MCF.WriteReg32 = LEWriteReg32;
MCF.ReadReg32  = LEReadReg32;
MCF.FlushLLCommands = LEFlushLLCommands;   // no-op for LinkE
MCF.SetupInterface = LESetupInterface;
MCF.Control3v3 / Control5v / ResetInterface / Exit / ...
```

`BlockWrite64` is **not** set for LinkE. Therefore flashing flows through the
slow-but-simple `DefaultWriteBinaryBlob` → `DefaultWriteWord` path, which writes
flash **one 32-bit word at a time** by running tiny RISC-V code out of the Debug
Module program buffer. That is the path we port — it needs no WCH bootloader blob
and no `BlockWrite64`.

So the whole job reduces to:

1. **USB plumbing** — `wch_link_command()` (bulk OUT then bulk IN on a vendor interface).
2. **Two DMI primitives** — `LEWriteReg32` / `LEReadReg32` (the `81 08 06 …` packet).
3. **Reimplement the generic Debug-Module algorithm in JS** — setup, halt,
   unlock, erase, word-write loop, wait-for-done, wait-for-flash, reboot.

---

## 2. USB topology / WebUSB mapping

libusb call (C) → WebUSB equivalent:

| minichlink (libusb) | WebUSB |
|---|---|
| `libusb_open` | `await device.open()` |
| (implicit) | `await device.selectConfiguration(1)` |
| `libusb_claim_interface(devh, 0)` | `await device.claimInterface(IFACE)` |
| `libusb_bulk_transfer(devh, 0x01, buf, len, …)` (OUT) | `await device.transferOut(EP_OUT, buf)` |
| `libusb_bulk_transfer(devh, 0x81, buf, len, …)` (IN) | `await device.transferIn(EP_IN, len)` |

Endpoints in C are hardcoded `0x01` OUT and `0x81` IN. The WCH-LinkE is a
**composite device** — and on the real hardware here the vendor interface
(iface 0, `interfaceClass === 0xff`) exposes **two** bulk pairs:

```
if0 cls=255 [in2:bulk, out2:bulk, in1:bulk, out1:bulk]   <- programmer (vendor)
if1 cls=2   [in4:interrupt]                              <- CDC-ACM control
if2 cls=10  [in3:bulk, out3:bulk]                        <- CDC data (serial)
```

So hardcoding `0x01`/`0x81` is wrong twice over (wrong iface possible, and two
candidate pairs on the right iface). The implemented approach:

- Pick the `interfaceClass === 0xff` interface, claim it, then
  `selectAlternateInterface(iface, 0)` (Chrome/Linux needs this before the
  endpoints carry data).
- **Probe** each (out, in) bulk pair with the "get version" handshake and keep
  the pair whose reply starts `0x82 0x0d …`. On this unit the answering pair is
  ep1 (`0x01`/`0x81`), but the probe makes it firmware-agnostic.
- `transferOut(n, …)` / `transferIn(n, …)` take the **endpoint number** (1), not
  the address (`0x81`); direction is implied by the method.

**Priming matters.** A bare version read on a freshly-opened programmer hangs
(the IN never completes). Sending `81 0d 01 ff` (stop) + a short throwaway IN
read first clears that state; *then* the version read answers. The probe does
exactly this stop→drain→version sequence per pair, which doubles as the C
"initial drain" (`pgm-wch-linke.c:264`).

> **No per-call timeout in WebUSB** (libusb had 5 s). Every `transferIn` is
> wrapped in a `Promise.race` timeout so a non-replying endpoint surfaces as an
> error instead of hanging forever.

WebUSB preconditions in `lib/main.js`:
`navigator.usb.requestDevice({filters:[{vendorId:0x1a86,productId:0x8010}]})`
— note WebUSB uses `vendorId`/`productId` (the `usbVendorId`/`usbProductId` keys
are WebSerial). The returned `USBDevice` is passed into
`wchlink({device, onProgress})`.

---

## 3. Protocol reference (the bytes we must emit)

### 3.1 `wchLinkCommand(out)` — control channel (EP1)

Mirrors `wch_link_command()` (`pgm-wch-linke.c:63`): write the command bytes to
bulk OUT, then read one bulk IN packet (≤ ~1024 bytes) as the reply. All control
commands start with `0x81`. Used for setup/power/version.

Commands we need (each is a byte string sent via `transferOut`):

| Bytes | Meaning |
|---|---|
| `81 0d 01 ff` | stop / exit programming mode |
| `81 0d 01 01` | reset programmer state, returns FW version (reply `82 0d 04 <maj> <min> <type>`; type `18`=LinkE) |
| `81 0d 01 02` | put target on hold / connect |
| `81 0c 02 01 02` | set SWD interface speed (default 4 MHz) |
| `81 0c 02 <chip_type> <speed>` | set speed for detected chip (`chip_type=0x09`, `speed=0x01` for V003) |
| `81 0d 01 09` / `81 0d 01 0a` | 3V3 target power on / off |
| `81 0d 01 0b` / `81 0d 01 0c` | 5V target power on / off |
| `81 06 01 01` | query read-protection status (reply byte[3]: 1=protected) |
| `81 0d 01 13` | force reset line low (used in retry dance) |
| `81 0b 01 01` | release reset / part of connect dance |

Note: for the **external-detection** path (what we use) `LESetupInterface`
mostly just runs the connect dance with `81 0d 01 02` and the speed command, then
hands off to the Debug-Module register writes. We can keep our `setupInterface`
minimal (see §5).

### 3.2 DMI register read/write — the workhorse (EP1)

This is the entire low level. From `LEWriteReg32` / `LEReadReg32`
(`pgm-wch-linke.c:294,318`):

```
write reg:  81 08 06 <reg7> <b3> <b2> <b1> <b0> 02      // op 2 = write, value big-endian
read  reg:  81 08 06 <reg7> 00  00  00  00  01          // op 1 = read
reply (9):  82 08 06 <reg7> <b3> <b2> <b1> <b0> <stat>  // value big-endian; stat 0=ok, 2/3=fail
```

`<reg7>` is a 7-bit RISC-V Debug Module register address. Reply must be 9 bytes;
`stat ∈ {2,3}` means error. (If the very first op errors and the programmer was
never initialized, C re-sends `81 0d 01 02` once — `LE_HANDLE_REG_ERROR`.)

So the JS primitives are:

```js
async writeReg32(reg7, val) { … send packet, check 9-byte reply, stat … }
async readReg32(reg7)       { … return (b3<<24)|(b2<<16)|(b1<<8)|b0 … }
```

`FlushLLCommands` is a **no-op** for LinkE (transfers are synchronous), so any
`flush()` calls in the ported algorithm become awaits / nothing.

### 3.3 Debug-Module register map (`minichlink.h:203`)

```
DMDATA0=0x04 DMDATA1=0x05 DMCONTROL=0x10 DMSTATUS=0x11 DMHARTINFO=0x12
DMABSTRACTCS=0x16 DMCOMMAND=0x17 DMABSTRACTAUTO=0x18 DMPROGBUF0..7=0x20..0x27
DMCPBR=0x7C DMCFGR=0x7D DMSHDWCFGR=0x7E DMCHIPID=0x7F
```

`DMCOMMAND` access-register encodings used:
- `0x002310NN` — copy DATA0 → register xNN (NN = 0x0a..0x0f for x10..x15).
- `0x00271008` — write DATA0 → x8 **and** execute program buffer.
- `0x00221008` — read x8 → DATA0.
- `0x00240000` — execute program buffer (no reg transfer).
- `0x00220000|csr` — read a CSR (e.g. marchid `0xf12`) → DATA0.

---

## 4. CH32V003 constants (inline the `chips.c` row)

```js
const CH32V003 = {
  family_id: 0x09,        // chip_type byte for the speed command
  flash_base: 0x08000000,
  flash_size: 16 * 1024,
  sector_size: 64,        // erase + program page granularity
  ram_base: 0x20000000,
  ram_size: 2048,
  interface_speed: 0x01,  // 81 0c 02 09 01
  no_autoexec: false,     // DMABSTRACTAUTO works -> use autoexec word-write
};
```

FLASH peripheral registers (used by the algorithm; addresses are absolute):

```
FLASH_STATR  = 0x4002200C   // bit0 BSY, bit4 WRPRTERR, bit15 BOOT_LOCK
FLASH_CTLR   = 0x40022010
FLASH_ADDR   = 0x40022014
FLASH_KEYR   = 0x40022004   // unlock: 0x45670123 then 0xCDEF89AB
FLASH_OBKEYR = 0x40022008   // 0x45670123 / 0xCDEF89AB
FLASH_MODEKEYR = 0x40022024 // 0x45670123 / 0xCDEF89AB  (fast prog unlock)
```

CTLR bits used: `CR_PAGE_PG=0x00010000 (FTPG)`, `CR_BUF_LOAD=0x00040000`,
`CR_BUF_RST=0x00080000`, `CR_PAGE_ER=0x00020000 (FTER)`, `CR_STRT=0x00000040`,
`CR_MER=0x00000004`.

---

## 5. End-to-end flash sequence (what `flush(bin)` does)

Ported from `DefaultSetupInterface` + `DefaultWriteBinaryBlob` +
`DefaultWriteWord` + `StaticUpdatePROGBUFRegs` + `InternalUnlockFlash` +
`DefaultErase` + `DefaultWaitForFlash` + `DefaultWaitForDoneOp` + `DefaultHaltMode`.

**A. Open & claim** (§2). Drain stale IN.

**B. Programmer setup** (`LESetupInterface`):
1. `81 0d 01 ff` (stop), `81 0d 01 01` (reset state, read version).
2. `81 0c 02 01 02` (default speed).
3. Connect dance: `81 0d 01 02` and retries (we can simplify to a couple tries).
4. `81 0c 02 09 01` (V003 speed).

**C. Debug-Module bring-up** (`DefaultSetupInterface` lines 1271-1310):
```
delay ~16ms
writeReg32(DMSHDWCFGR, 0x5aa50000 | (1<<10))   // x2
writeReg32(DMCFGR,     0x5aa50000 | (1<<10))    // x2
writeReg32(DMCONTROL,  0x80000001)              // x3  (haltreq)
readReg32(DMSTATUS) -> must be != 0x00000000 and != 0xffffffff   (retry 3x)
```

**D. Halt + reset** (`DefaultHaltMode` HALT_AND_RESET):
```
writeReg32(DMSHDWCFGR, 0x5aa50000|(1<<10))
writeReg32(DMCFGR,     0x5aa50000|(1<<10))
writeReg32(DMCONTROL,  0x80000001)
writeReg32(DMCONTROL,  0x80000003)   // reset
writeReg32(DMCONTROL,  0x80000001)   // x2 re-halt
delay 10ms
```

**E. (optional) chip-id sanity** — read marchid via
`DMCOMMAND=0x00220f12` then `DMDATA0`; or read the `0x7f` reg. For v1 we may
skip real detection and just assume CH32V003 (the connect already implies it),
but reading `DMSTATUS`/marchid is a good liveness check.

**F. Unlock flash** (`InternalUnlockFlash`, line 2560):
```
readWord(FLASH_CTLR)                         // see §6 for readWord/writeWord
writeWord(FLASH_KEYR,   0x45670123); writeWord(FLASH_KEYR,   0xCDEF89AB)
writeWord(FLASH_OBKEYR, 0x45670123); writeWord(FLASH_OBKEYR, 0xCDEF89AB)
writeWord(FLASH_MODEKEYR,0x45670123); writeWord(FLASH_MODEKEYR,0xCDEF89AB)
readWord(FLASH_CTLR) -> LOCK bits must be clear
```

**G. Write the blob, sector by sector** (`DefaultWriteBinaryBlob`, no
`BlockWrite64`, V003 branch). For each 64-byte sector covering the image
(pad tail with `0xFF`):
```
if sector not known-erased: Erase(base, 64, type=0)      // §H
writeWord(FLASH_CTLR, CR_PAGE_PG)                        // 0x00010000
writeWord(FLASH_CTLR, CR_BUF_RST | CR_PAGE_PG)           // 0x00090000
waitForFlash()
for j in 0..15:                                          // 16 words = 64 bytes
    writeWord(base + j*4, word_j)   // progbuf word-write w/ autoexec; see §6
writeWord(FLASH_ADDR, base)
writeWord(FLASH_CTLR, CR_PAGE_PG | CR_STRT)              // 0x00010040  -> commit page
waitForFlash()
mark sector not-erased
```

**H. Erase** (`DefaultErase` fast-page, type 0, line 2607):
```
ensure unlocked
writeWord(FLASH_CTLR, CR_PAGE_ER)            // 0x00020000  (FTER)
writeWord(FLASH_ADDR, chunk)
writeWord(FLASH_CTLR, CR_STRT | CR_PAGE_ER)  // 0x00020040
waitForFlash()
```
(Whole-chip erase, type 1: `CTLR=0`, `CTLR=CR_MER`, `CTLR=CR_STRT|CR_MER`,
wait — optional convenience.)

**I. Verify** — `readBinaryBlob` back (§6 read path) and compare. Optional but
cheap and worth it.

**J. Reboot target** (`DefaultHaltMode` HALT_MODE_REBOOT):
```
writeReg32(DMCONTROL, 0x80000001)  // x2
writeReg32(DMCONTROL, 0x80000003)  // reset
writeReg32(DMCONTROL, 0x40000001)  // resumereq
```

**K. Exit** — `81 0d 01 ff`; (optionally power off); `device.releaseInterface` /
`device.close()`.

---

## 6. The word-write / word-read mechanism (most subtle part)

`writeWord(addr,val)` does **not** map to a USB command. It builds a 2-instruction
RISC-V routine in the program buffer and uses the Debug Module's *autoexec* so
that each subsequent `DMDATA0` write re-runs it. From `DefaultWriteWord`
(line 1956) + `StaticUpdatePROGBUFRegs` (line 1763).

**One-time progbuf register prep** (`StaticUpdatePROGBUFRegs`), do once per
write/read "sequence" (state tag changes):
```
readReg32(DMHARTINFO) -> rr ; data0addr = 0xe0000000 | (rr & 0x7ff)
writeReg32(DMABSTRACTAUTO, 0)
writeReg32(DMDATA0, data0addr);     writeReg32(DMCOMMAND, 0x0023100a) // x10 = &DATA0
writeReg32(DMDATA0, data0addr+4);   writeReg32(DMCOMMAND, 0x0023100b) // x11 = &DATA1
writeReg32(DMDATA0, 0x4002200c);    writeReg32(DMCOMMAND, 0x0023100c) // x12 = &FLASH_STATR
writeReg32(DMDATA0, 0x00050000);    writeReg32(DMCOMMAND, 0x0023100d) // x13 = PAGE_PG|BUF_LOAD
```
(`0x00050000` = `CR_PAGE_PG(0x10000) | CR_BUF_LOAD(0x40000)`.)

**Enter write sequence** (first write, or when switching flash↔ram):
```
writeReg32(DMABSTRACTAUTO, 0)
(StaticUpdatePROGBUFRegs if coming from a read/none state)
// progbuf: load val (x8) and addr (x9), store, post-increment addr
writeReg32(DMPROGBUF0, 0x41844100) // c.lw x8,0(x10) ; c.lw x9,0(x11)
writeReg32(DMPROGBUF1, 0x0491c080) // c.sw x8,0(x9) ; c.addi x9,4
// FLASH (V003) tail: ack page-write + spin on BSY:
writeReg32(DMPROGBUF2, 0x0001c184) // c.sw x9,0(x11) ; c.nop
writeReg32(DMPROGBUF3, 0x4200c254) // c.sw x13,4(x12) ; c.lw x8,0(x12)
writeReg32(DMPROGBUF4, 0xfc758805) // c.andi x8,1 ; c.bnez x8,-4   (BSY spin)
writeReg32(DMPROGBUF5, 0x90029002) // c.ebreak ; c.ebreak
writeReg32(DMDATA1, addr)
writeReg32(DMDATA0, val)
writeReg32(DMCOMMAND, 0x00240000)  // execute once
writeReg32(DMABSTRACTAUTO, 1)      // enable autoexec
// flash: waitForDoneOp()
```
For a **non-flash** (RAM) write the progbuf2 is just `0x9002c184`
(`c.sw x9,0(x11); c.ebreak`) and no autoexec/wait needed.

**Subsequent words in the same sequence** (the fast path): just
```
if addr != expected: writeReg32(DMDATA1, addr)
writeReg32(DMDATA0, val)   // autoexec re-runs the routine
if flash: waitForDoneOp()
```
Track `currentstateval` (= next expected addr, advance by 4) and a `statetag`
(`"WRSQ"` vs `"RDSQ"`) exactly like the C, so we know when to rebuild progbuf.

**`readWord(addr)`** (`DefaultReadWord`, line 2479) is the symmetric routine:
prep `x10`, load progbuf with `c.lw x8,0(x10); c.ebreak` style, set `DMDATA0=addr`,
`DMCOMMAND` execute, then `0x00221008` to copy x8→DATA0 and `readReg32(DMDATA0)`.
For flash control registers (`0x40022010`, `0x4002200C`, …) the C has a guarded
path — reading these works the same, just don't enable autoexec across them.

**`waitForDoneOp()`** (line 1232): poll `readReg32(DMABSTRACTCS)` until busy
bit `(1<<12)` clears (timeout 100); if `((cs>>8)&7)!=0` it's a fault — clear with
`writeReg32(DMABSTRACTCS, 0x00000700)` and return error.

**`waitForFlash()`** (line 1201): poll `readWord(FLASH_STATR)` until `& 3 == 0`
(BSY clear), timeout ~1000; if `& WRPRTERR(0x10)` → protection error.

> Implementation tip: this autoexec/state-tag bookkeeping is the part most likely
> to have bugs. Start with a **dumb, correct** variant — rebuild the progbuf and
> issue an explicit `DMCOMMAND=0x00240000` execute for *every* word, no autoexec,
> `waitForDoneOp` after each. It's slower (16 KB still flashes in a couple
> seconds) but far easier to get right. Add autoexec batching only once the dumb
> path verifies.

---

## 6b. NRST as GPIO (the pre-flash unlock)

The CH32V003 NRST pin (PD7) can be reclaimed as GPIO by clearing the `RST_MODE`
bit in the USER option byte. We do this **before flashing** — and as a side
effect the option-byte rewrite resets `RDPR` to unprotected (`0xA5`) and triggers
a **full chip mass-erase**, so the one command also serves as the unlock that
lets a factory-fresh (read-protected) chip be programmed.

> Naming note: this is minichlink's `-D` (`minichlink.c:363` →
> `MCF.ConfigureNRSTAsGPIO`). It is **not** the read-protection `-p`/`-P` flags
> (`ConfigureReadProtection`) — we don't use those.

> WARNING: this writes option bytes and therefore **mass-erases flash**. Existing
> firmware is destroyed. That's intended here (we flash right after).

### What runs (LinkE firmware-assisted)

For CH32V003 the LinkE driver sets `MCF.ConfigureNRSTAsGPIO =
LEConfigureNRSTAsGPIO` (`pgm-wch-linke.c:718`). The firmware does the option-byte
erase + rewrite internally — two control commands
(`LEConfigureNRSTAsGPIO`, `pgm-wch-linke.c:640`):

```
81 06 08 02 ff ff ff ff ff ff ff     // write option bytes, op 02, USER=0xff -> NRST as GPIO
81 0b 01 01                          // apply + reset
```

Byte layout of the first command: `81 06 <len=08> <op=02> <USER> <other OB...>`.
`USER=0xff` selects NRST-as-GPIO; `USER=0xf7` keeps NRST as reset (the
`one_if_yes_gpio` arg toggles exactly this byte). No `81 11 01 09` prefix is
needed (that prefix belongs to the read-protection path, which we dropped).

### Sequence around it

1. `HaltMode(HALT_AND_RESET)` (§D).
2. The two commands above.
3. **Re-init.** Chip was mass-erased and reset; option bytes latch on reset.
   Re-run §B→§D before programming.
4. Proceed to unlock/erase/write (§F→).

---

## 7. Proposed JS module shape

Entrypoint (as implemented): `export const wchlink = async ({device, onProgress})`
returning `{programmerInfo, chipInfo, nrstAsGpio, writeImage, close}`. Internally
split into small closures matching the layers:

```
lib/wchlink.js            // public: wchlink({device, onProgress}) -> { programmerInfo, chipInfo, nrstAsGpio, writeImage, close }
  └ transport: open/claim/drain, transferOut, transferIn(+timeout)
  └ link:      wchLinkCommand(bytes), setSpeed, power3v3, version, connectDance
  └ dmi:       writeReg32(reg,val), readReg32(reg)         // §3.2
  └ dm:        setupDM, halt(mode), readWord, writeWord, waitForDoneOp, waitForFlash   // §6
  └ option:    nrstAsGpio() (2 cmds + re-init; also unlocks + mass-erases)   // §6b
  └ flash:     unlock, eraseSector, writeImage(bytes), verify   // §5
  └ writeImage(bytes): orchestrate F→K, report progress per sector
```

Helpers: a `u32le`/`u32be` pack/unpack, a `delay(ms)`, and a constants module.
`bin` arrives as `ArrayBuffer`/`Uint8Array` (from `fetch`/file input); base is
`0x08000000`; pad to 64-byte multiple with `0xFF`.

`onProgress({phase, done, total})` so `main.js` can drive the xterm/console UI
that's already wired in the Expander tab.

---

## 8. WebUSB gotchas / risks (and how they bit us)

- **No transfer timeout.** `transferIn` blocks until data or stall. Every read is
  wrapped in a `Promise.race` timeout; on timeout we surface an error (or ignore,
  for the probe/drain). *This was the original "blank console" hang.*
- **Endpoint discovery, not hardcoding** — composite device with TWO bulk pairs on
  the vendor iface (§2). We probe + lock the pair that answers the version
  handshake. *Hardcoding ep1 worked here, but the probe is the safe path.*
- **Priming the programmer** (§2) — a bare version read on a fresh open hangs;
  `81 0d 01 ff` + a throwaway IN read first unsticks it.
- **`selectAlternateInterface(iface, 0)`** after claim — Chrome/Linux often needs
  it before endpoints carry data.
- **Reply framing.** Each control command expects exactly one IN packet; for DMI
  ops the reply is 9 bytes. Read with a generous length (e.g. 64) and slice.
- **`device.open()` can throw** if the OS/another tab holds the device. On Linux
  the kernel `cdc_acm` driver may claim the *CDC* interface (a different iface —
  harmless), but a udev rule (`web2/99-minichlink.rules` equivalent) is typically
  needed so the browser can access the *vendor* iface.
- **Reset semantics differ.** WebUSB has no `libusb_reset_device`; rely on the
  `81 0d 01 ff` / `DMCONTROL` reset commands only.
- **Endianness:** DMI value bytes are **big-endian on the wire** (§3.2), but the
  flash image and FLASH register values are little-endian RISC-V words. Keep the
  two conversions separate and well-named.
- **No ARM/IAP recovery** in v1: if the LinkE is in ARM mode (pid `0x8012`) or IAP
  (`4348:55e0`), `requestDevice` with our filter won't even find it. Document that
  the user must use it in RISC-V mode.

---

## 9. Milestones

1. ✅ **Transport + link** — open/claim/probe, `cmd()`, FW version (`81 0d 01 01`).
2. ✅ **DMI primitives** — `writeReg32`/`readReg32`; DM bring-up (§C), halt/reset.
3. ✅ **NRST as GPIO** (§6b) — 2-command option-byte write + re-init (unlocks +
   mass-erases). Runs before flashing.
4. ✅ **readWord** — used by `chipInfo` (UUID) and by verify.
5. ✅ **Erase + dumb writeWord** (§6 tip) — per-sector erase + word write.
6. ✅ **Full `writeImage(bytes)`** — sector loop, pad to 64 B, progress, readback
   verify, reboot. Confirmed on hardware.
7. ⬜ **Optimize** (optional) — autoexec batching, fewer round-trips. Only worth it
   for large images; the "dumb" per-word path is fine for the small Expander fw.

Implemented in `lib/wchlink.js`, driven from `lib/main.js` (Expander tab), which
wires `onProgress` into the in-page console.

---

## 10. Reference index (line numbers in `ch32fun/minichlink/`)

- `pgm-wch-linke.c:63` `wch_link_command` — USB OUT/IN framing
- `pgm-wch-linke.c:294` `LEWriteReg32`, `:318` `LEReadReg32` — DMI packet (§3.2)
- `pgm-wch-linke.c:360` `LESetupInterface` — connect dance / speed
- `pgm-wch-linke.c:606/617` `LEControl3v3/5v` — target power
- `pgm-wch-linke.c:640` `LEConfigureNRSTAsGPIO` — NRST-as-GPIO 2-cmd (§6b)
- `minichlink.c:363` `-D` arg → `ConfigureNRSTAsGPIO(dev,1)` (§6b)
- `minichlink.c:1271` `DefaultSetupInterface` — DM bring-up (§C)
- `minichlink.c:1763` `StaticUpdatePROGBUFRegs` — progbuf reg prep (§6)
- `minichlink.c:1956` `DefaultWriteWord` — word write via progbuf+autoexec (§6)
- `minichlink.c:2479` `DefaultReadWord` — word read (§6)
- `minichlink.c:2070` `DefaultWriteBinaryBlob` — sector loop (§G)
- `minichlink.c:2560` `InternalUnlockFlash` — key sequence (§F)
- `minichlink.c:2607` `DefaultErase` — page/whole erase (§H)
- `minichlink.c:1201` `DefaultWaitForFlash`, `:1232` `DefaultWaitForDoneOp`
- `minichlink.c:3101` `DefaultHaltMode` — halt/reset/reboot (§D,§J)
- `chips.c:3` `ch32v003` row — sizes/speed (§4)
- `minichlink.h:203` DM register defines (§3.3)
</content>
</invoke>

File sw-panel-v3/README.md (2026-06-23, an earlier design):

esp-idf v6.0

```bash
cd ~/work/github/espressif/esp-idf
git pull
git submodule update --init --recursive
./install.sh esp32c6

cd ~/work/github/AI6YP/XAPOH/sw-panel-v3
. ~/work/github/espressif/esp-idf/export.sh

idf.py set-target esp32c6

idf.py build # just build

idf.py -p /dev/ttyACM0 flash # build & flash

idf.py -p /dev/ttyACM0 flash monitor # build & flash & monitor -> exit Ctrl+]
```

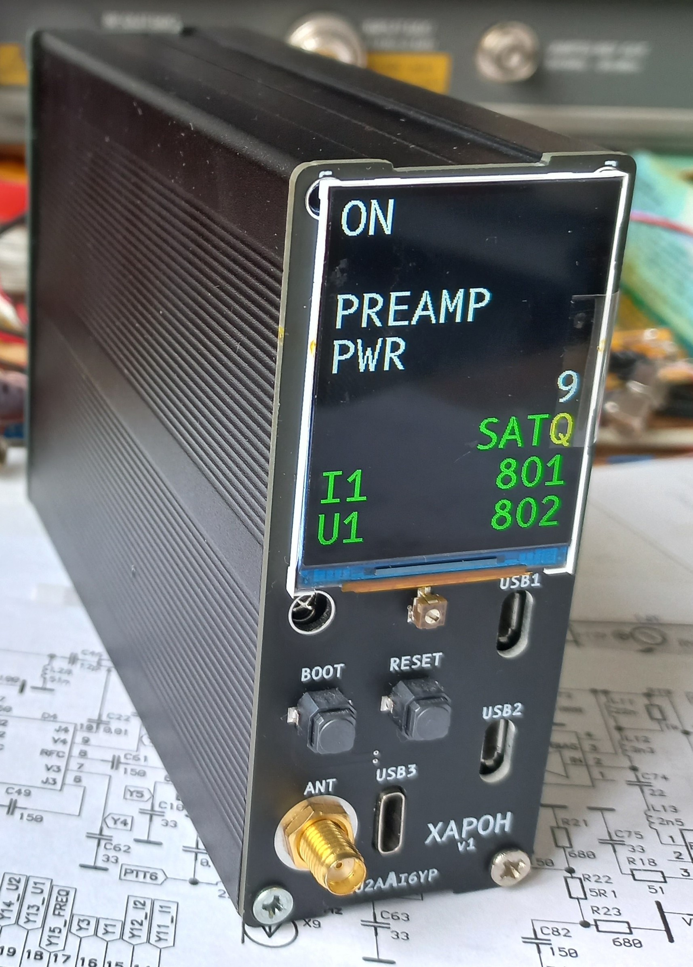
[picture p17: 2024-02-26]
assets/трансивер.jpg

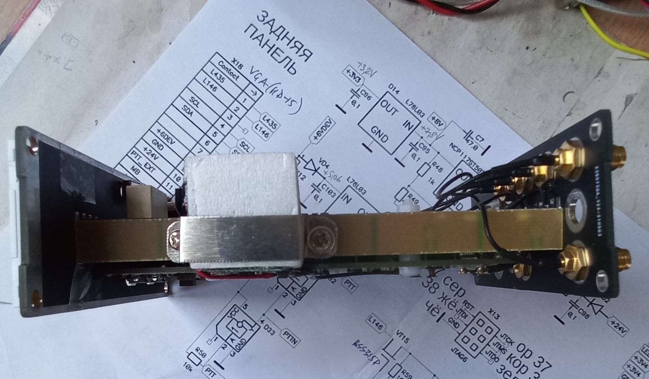
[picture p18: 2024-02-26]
assets/XAPOH N4i.jpg

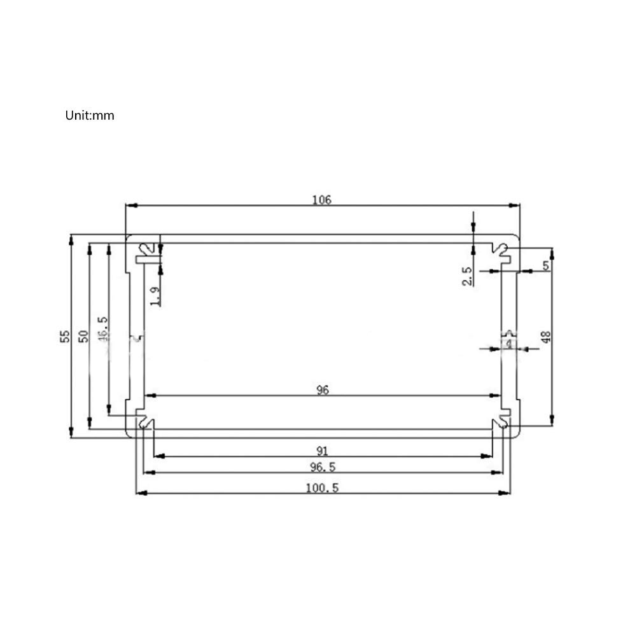
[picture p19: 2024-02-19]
assets/case2.jpg

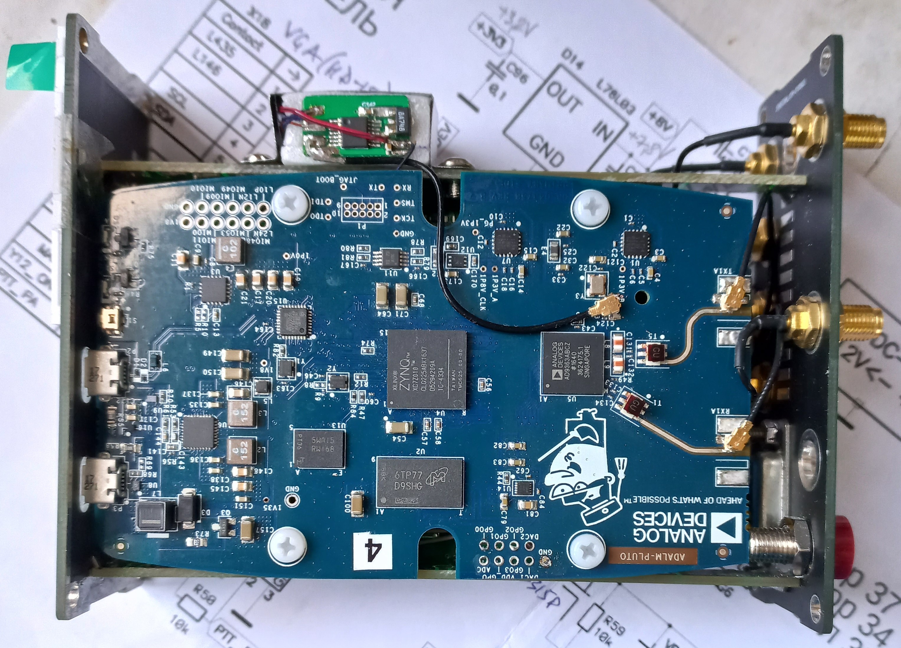
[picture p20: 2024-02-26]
assets/XAPOH N4k.jpg

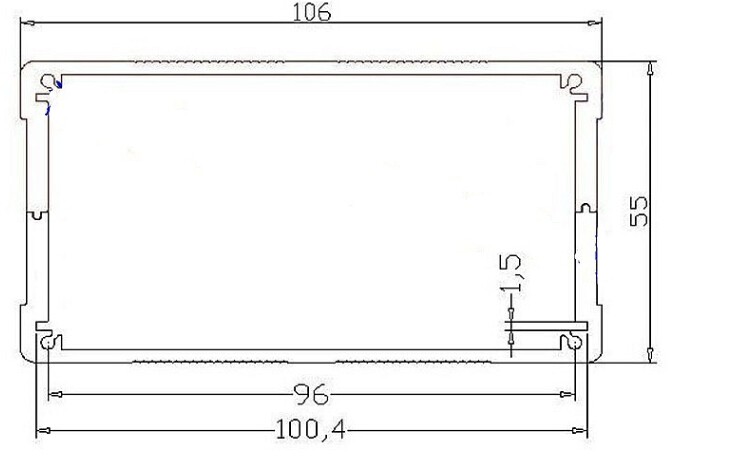
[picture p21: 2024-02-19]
assets/case3.jpg

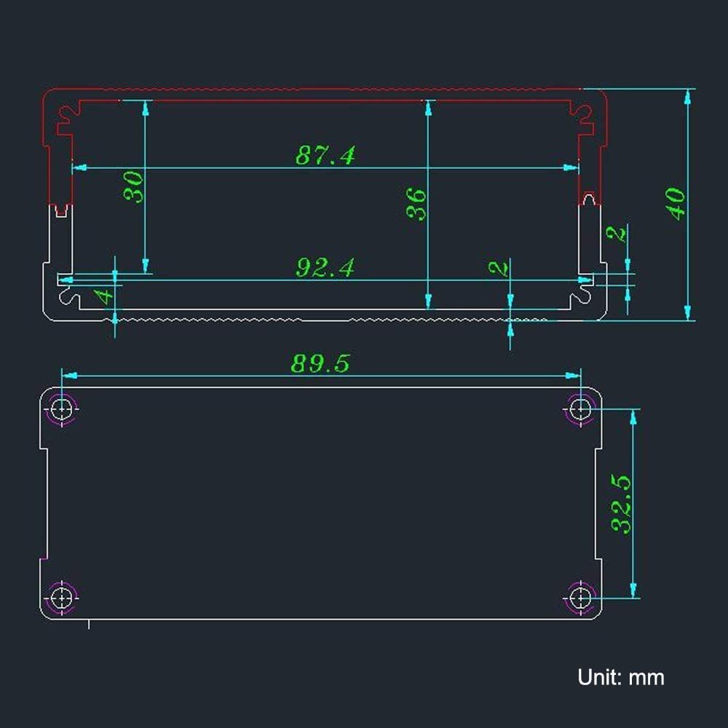
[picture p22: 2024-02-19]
assets/case1.jpg

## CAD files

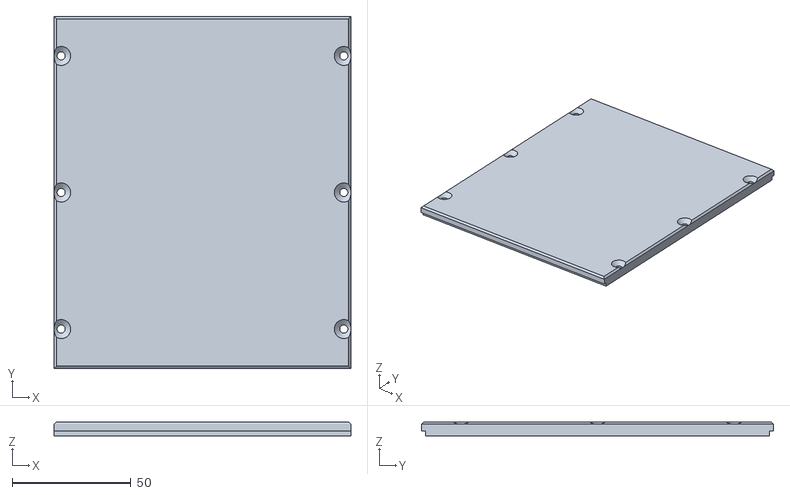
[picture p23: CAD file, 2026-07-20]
3d/xapoh-case-TP-v1.0.0.stl
125.0 x 148.2 x 6.00

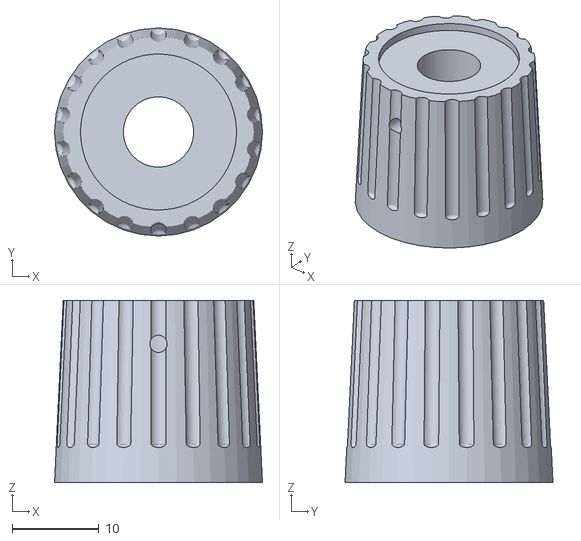
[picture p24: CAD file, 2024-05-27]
knob/knob-outer-v1.stl
24.0 x 24.0 x 21.0

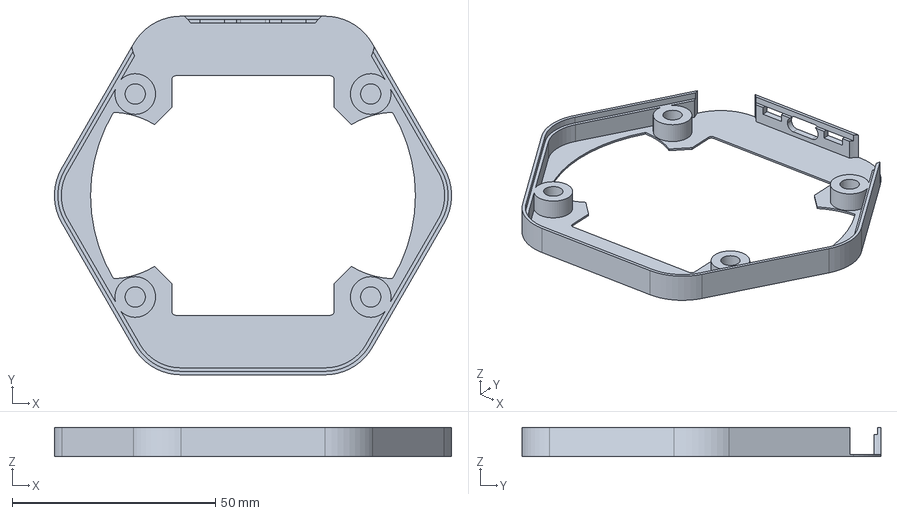
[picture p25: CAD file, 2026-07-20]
3d/face-v12.1.0.step
97.8 x 88.3 x 7.20 mm

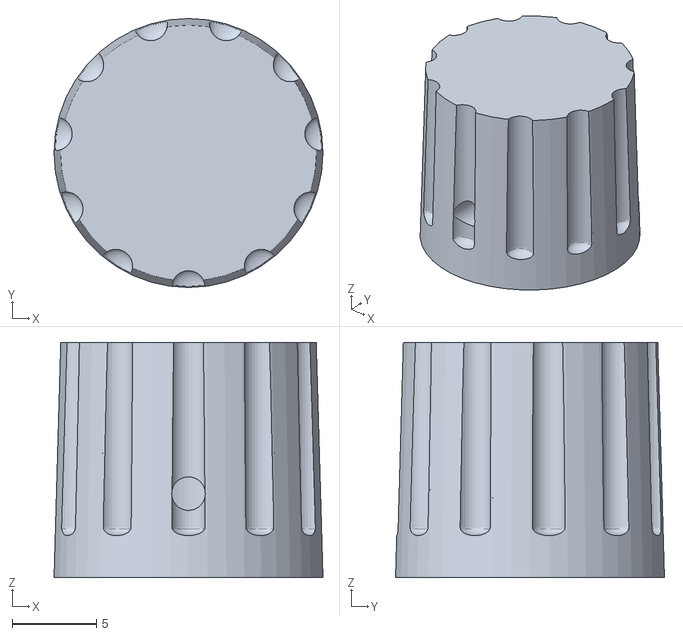
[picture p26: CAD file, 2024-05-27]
knob/knob-inner-v1.stl
16.0 x 16.0 x 14.0

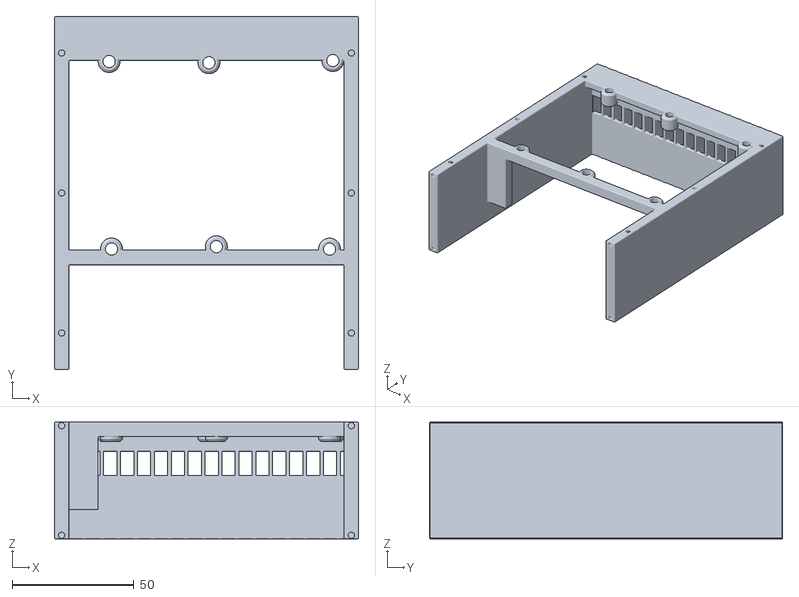
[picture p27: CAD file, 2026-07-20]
3d/xapoh-case-frame-v1.0.0.stl
125.0 x 145.0 x 48.0

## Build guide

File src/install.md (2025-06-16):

---
title: Install
style: style.css
toc: false
---

```js
import {Mutable} from "observablehq:stdlib";
import {bins} from './components/bins.js';
import {configEditor} from './components/config-editor.js';
import {onEspConnectClick, onResetClick, onProgramClick, onProgressBar, xterm} from './components/esp-install.js';

const xterm0 = xterm();
```

# Install software

```js
const esp = view(Inputs.button(
  html`Connect to board`,
  {value: null, reduce: () => onEspConnectClick(xterm0)}
));
```

```js
const resetButton = view(Inputs.button('Reset', {
  disabled: (esp === null),
  value: null, reduce: () => onResetClick(esp)
}));
```

```js
const cfg = view(configEditor());
```

```js
const programButton = view(Inputs.button('Program Firmware: ' + bins[0].time, {
  disabled: (esp === null),
  value: null,
  reduce: () =>
    onProgramClick(esp, cfg)
}));
```

```js
const progressBar = Generators.observe(onProgressBar);
```

${progressBar.fileIndex} : ${Math.round(100 * progressBar.written / progressBar.total)}%

```js
xterm0.div
```

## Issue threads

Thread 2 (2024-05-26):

XAPOH v9.1.1 FW features

drom, 2024-05-26:
Panel

* [ ] LCD driver
* [ ] I2C master driver
* [ ] UART programmer
* [ ] IR receiver
* [ ] Encoder driver
* [ ] Free RTOS

Main board

* [ ] I2C slave driver
* [ ] store defaults in FLASH

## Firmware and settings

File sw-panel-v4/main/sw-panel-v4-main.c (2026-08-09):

#include <stdint.h>
#include <string.h>

#include "freertos/FreeRTOS.h"
#include "freertos/task.h"
#include "freertos/event_groups.h"

#include "esp_err.h"
#include "esp_log.h"
#include "esp_event.h"
#include "esp_system.h"
#include "esp_partition.h"
#include "nvs_flash.h"

#include "driver/gpio.h"
#include "driver/rmt_tx.h"
#include "driver/usb_serial_jtag.h"

#include "led_strip_encoder.h"

// WIFI
#include "esp_wifi.h"
#include "esp_tls_crypto.h"
#include "esp_http_server.h"

#include "lwip/err.h"
#include "lwip/sys.h"

#include "sdkconfig.h"

#include "pages.h"
#include "link.h"
#include "swio_programmer.h"
#include "expander_image.h" // const unsigned char expander_bin[]; expander_bin_length

#define RMT_LED_STRIP_RESOLUTION_HZ 10000000 // 10MHz, 1 tick = 0.1us
#define RMT_LED_STRIP_GPIO_NUM      8
#define NUM_LEDS 11

// v4: 3 point-to-point links to the CH32V003 expanders (was I2C SDA/SCL),
// gpio0/1/2 — see link.c. Same gpio is SWIO in program mode, UART TX in operation.
#define FRAME_SYNC 0xAA

// GPIO3: external VCC switch control (0 = 5V normal operation, 1 = 3.3V programming mode)
#define VCC_SWITCH_GPIO 3

static const char *TAG = "XAPOH";

// Embedded CH32V003 image (sw-v4/main.bin) — compiled in via expander_image.h
// (generated by sw-panel-v4/bin-to-h.js). Flashed on explicit command only.

static EventGroupHandle_t s_wifi_event_group;
#define WIFI_CONNECTED_BIT BIT0
#define WIFI_FAIL_BIT      BIT1

struct app_context_s {
  uint8_t pixels[NUM_LEDS * 3];
  const void *config_ptr;
};
typedef struct app_context_s app_context_t;

static app_context_t cntxt0;
static rmt_channel_handle_t led_chan = NULL;
static rmt_encoder_handle_t led_encoder0 = NULL;
static rmt_transmit_config_t tx_config = { .loop_count = 0 };
static int s_retry_num = 0;

// --- expander link ----------------------------------------------------------
// Send the full-state frame (0xAA b0 b1 b2 csum) to expander `idx` (0..2).
static void send_expander(int idx, uint8_t b0, uint8_t b1, uint8_t b2) {
  if (idx < 0 || idx > 2) return;
  uint8_t frame[5] = {FRAME_SYNC, b0, b1, b2, (uint8_t)(b0 ^ b1 ^ b2)};
  link_send(idx, frame, sizeof(frame));
}

// --- WiFi -------------------------------------------------------------------
static void event_handler(void* arg, esp_event_base_t event_base, int32_t event_id, void* event_data) {
  if (event_base == WIFI_EVENT && event_id == WIFI_EVENT_STA_START) {
    esp_wifi_connect();
  } else if (event_base == WIFI_EVENT && event_id == WIFI_EVENT_STA_DISCONNECTED) {
    if (s_retry_num < 100) {
      esp_wifi_connect();
      s_retry_num++;
      ESP_LOGI(TAG, "retry to connect to the AP");
    } else {
      xEventGroupSetBits(s_wifi_event_group, WIFI_FAIL_BIT);
    }
  } else if (event_base == IP_EVENT && event_id == IP_EVENT_STA_GOT_IP) {
    ip_event_got_ip_t* event = (ip_event_got_ip_t*) event_data;
    ESP_LOGI(TAG, "got ip:" IPSTR, IP2STR(&event->ip_info.ip));
    s_retry_num = 0;
    xEventGroupSetBits(s_wifi_event_group, WIFI_CONNECTED_BIT);
  }
}

void wifi_init_sta(app_context_t *cntxt) {
  s_wifi_event_group = xEventGroupCreate();
  ESP_ERROR_CHECK(esp_netif_init());
  ESP_ERROR_CHECK(esp_event_loop_create_default());
  esp_netif_create_default_wifi_sta();

  wifi_init_config_t cfg = WIFI_INIT_CONFIG_DEFAULT();
  ESP_ERROR_CHECK(esp_wifi_init(&cfg));

  esp_event_handler_instance_t instance_any_id, instance_got_ip;
  ESP_ERROR_CHECK(esp_event_handler_instance_register(WIFI_EVENT, ESP_EVENT_ANY_ID, &event_handler, NULL, &instance_any_id));
  ESP_ERROR_CHECK(esp_event_handler_instance_register(IP_EVENT, IP_EVENT_STA_GOT_IP, &event_handler, NULL, &instance_got_ip));

  wifi_config_t wifi_config = {0};
  memcpy(&wifi_config.sta.ssid, (char *)cntxt->config_ptr, sizeof(wifi_config.sta.ssid));
  memcpy(&wifi_config.sta.password, ((char *)cntxt->config_ptr) + 32, sizeof(wifi_config.sta.password));

  ESP_ERROR_CHECK(esp_wifi_set_mode(WIFI_MODE_STA));
  ESP_ERROR_CHECK(esp_wifi_set_config(WIFI_IF_STA, &wifi_config));
  ESP_ERROR_CHECK(esp_wifi_start());
  ESP_LOGI(TAG, "wifi_init_sta finished.");

  EventBits_t bits = xEventGroupWaitBits(
    s_wifi_event_group, WIFI_CONNECTED_BIT | WIFI_FAIL_BIT, pdFALSE, pdFALSE, portMAX_DELAY);
  if (bits & WIFI_CONNECTED_BIT) {
    ESP_LOGI(TAG, "connected to ap");
  } else {
    ESP_LOGE(TAG, "wifi connect failed");
  }
}

// --- HTTP / WS --------------------------------------------------------------
esp_err_t index_get_handler(httpd_req_t *req) {
  httpd_resp_send(req, PAGE_index, PAGE_index_length);
  return ESP_OK;
}

// WS message protocol (operation mode, over WiFi):
//   [255, ...30 led bytes]      -> RGB strip
//   [target(0..2), b0, b1, b2]  -> push expander full-state
esp_err_t msg_handler(httpd_req_t *req) {
  if (req->method == HTTP_GET) return ESP_OK; // handshake

  httpd_ws_frame_t ws_pkt;
  memset(&ws_pkt, 0, sizeof(ws_pkt));
  ws_pkt.type = HTTPD_WS_TYPE_BINARY;
  esp_err_t ret = httpd_ws_recv_frame(req, &ws_pkt, 0);
  if (ret != ESP_OK) return ret;

  if (ws_pkt.len) {
    uint8_t *buf = calloc(ws_pkt.len, 1);
    if (!buf) return ESP_ERR_NO_MEM;
    ws_pkt.payload = buf;
    ret = httpd_ws_recv_frame(req, &ws_pkt, ws_pkt.len);
    if (ret != ESP_OK) { free(buf); return ret; }

    if (buf[0] == 255) { // RGB
      size_t n = ws_pkt.len - 1;
      if (n > sizeof(cntxt0.pixels)) n = sizeof(cntxt0.pixels);
      memcpy(cntxt0.pixels, buf + 1, n);
      ESP_ERROR_CHECK(rmt_transmit(led_chan, led_encoder0, cntxt0.pixels, sizeof(cntxt0.pixels), &tx_config));
      ESP_ERROR_CHECK(rmt_tx_wait_all_done(led_chan, portMAX_DELAY));
    } else if (ws_pkt.len >= 4 && buf[0] < 3) { // expander state
      send_expander(buf[0], buf[1], buf[2], buf[3]);
    }
    free(buf);
  }

  ws_pkt.payload = NULL;
  ws_pkt.len = 0;
  return httpd_ws_send_frame(req, &ws_pkt);
}

httpd_uri_t uri_get = { .uri = "/", .method = HTTP_GET, .handler = index_get_handler, .user_ctx = NULL };
httpd_uri_t msg_get = { .uri = "/dev1", .method = HTTP_GET, .handler = msg_handler, .user_ctx = NULL, .is_websocket = true };
httpd_uri_t msg_post = { .uri = "/dev1", .method = HTTP_POST, .handler = msg_handler, .user_ctx = NULL, .is_websocket = true };

httpd_handle_t start_webserver(void) {
  httpd_config_t config = HTTPD_DEFAULT_CONFIG();
  config.stack_size = 16384;
  httpd_handle_t server = NULL;
  if (httpd_start(&server, &config) == ESP_OK) {
    httpd_register_uri_handler(server, &uri_get);
    httpd_register_uri_handler(server, &msg_get);
    httpd_register_uri_handler(server, &msg_post);
  }
  return server;
}

void config_map_init(app_context_t *cntxt) {
  const esp_partition_t *config_partition = esp_partition_find_first(
    ESP_PARTITION_TYPE_DATA, ESP_PARTITION_SUBTYPE_ANY, "config");
  assert(config_partition != NULL);
  esp_partition_mmap_handle_t h;
  ESP_ERROR_CHECK(esp_partition_mmap(config_partition, 0, config_partition->size,
    ESP_PARTITION_MMAP_DATA, &cntxt->config_ptr, &h));
}

// --- expander flashing (program mode, USB-serial command) -------------------
// web4 sends a 2-byte command over USB-serial (WebSerial): 'F' then '0'|'1'|'2'|'A'.
// ESP flashes its embedded image via SWIO. Explicit-only; in operation there is
// no USB host, so no command ever arrives.
static void flash_one(int idx) {
  size_t len = expander_bin_length;
  int gpio = link_gpio_num(idx);
  ESP_LOGW(TAG, "FLASH expander %d (gpio%d), %u bytes", idx, gpio, (unsigned)len);

  ESP_LOGW(TAG, "Switching to 3.3V programming mode");

  // Switch to 3.3V programming mode
  gpio_set_level(VCC_SWITCH_GPIO, 1);
  vTaskDelay(pdMS_TO_TICKS(300));

  ESP_LOGW(TAG, "Flashing expander");

  link_flash_begin(idx);        // take the link, hand the raw pin to SWIO
  esp_err_t r = swio_flash_image(gpio, expander_bin, len);
  link_flash_end(idx);          // restore UART-TX idle-high, release the link

  ESP_LOGW(TAG, "Switching back to 5V normal operation");

  // Wait before switching back to 5V normal operation
  vTaskDelay(pdMS_TO_TICKS(300));
  gpio_set_level(VCC_SWITCH_GPIO, 0);

  ESP_LOGW(TAG, "FLASH expander %d -> %s", idx, esp_err_to_name(r));
}

static void flash_cmd_task(void *arg) {
  usb_serial_jtag_driver_config_t cfg = USB_SERIAL_JTAG_DRIVER_CONFIG_DEFAULT();
  if (usb_serial_jtag_driver_install(&cfg) != ESP_OK) {
    ESP_LOGE(TAG, "usb_serial_jtag install failed; flash command disabled");
    vTaskDelete(NULL);
    return;
  }
  uint8_t c;
  for (;;) {
    if (usb_serial_jtag_read_bytes(&c, 1, portMAX_DELAY) != 1) continue;
    if (c != 'F') continue;
    if (usb_serial_jtag_read_bytes(&c, 1, pdMS_TO_TICKS(1000)) != 1) continue;
    switch (c) {
      case '0': flash_one(0); break;
      case '1': flash_one(1); break;
      case '2': flash_one(2); break;
      case 'A': flash_one(0); flash_one(1); flash_one(2); break;
      // Physical bring-up probe: drive gpio0/1/2 directly (bypass the SWIO
      // bit-bang) so we can confirm the pad + read path are alive before
      // debugging protocol. From web4 send 'S0' / 'S1' / 'S2'.
      // Phase C logs the pin level 10x over 5s — short the gpio to GND by hand
      // in that window; the log MUST flip to 0. If it stays 1, the ESP read
      // path / pad / wiring is the problem, not the SWIO code.
      case 's': case 'S': {
        if (usb_serial_jtag_read_bytes(&c, 1, pdMS_TO_TICKS(1000)) != 1) break;
        int idx = c - '0';
        if (idx >= 0 && idx <= 2) {
          int g = link_gpio_num(idx);
          link_flash_begin(idx);
          swio_pin_selftest(g);
          link_flash_end(idx);
        }
        break;
      }
      // "Listen" probe for the reflash-running-chip problem (plan risk #3):
      // hammers connect() for 15s so you can power-cycle the CH32 mid-probe.
      // If it answers right after the CH32's reset (before it reaches __WFI),
      // the debug tap is alive at boot but gated during WFI sleep.
      case 'l': case 'L': {
        if (usb_serial_jtag_read_bytes(&c, 1, pdMS_TO_TICKS(1000)) != 1) break;
        int idx = c - '0';
        if (idx >= 0 && idx <= 2) {
          link_flash_begin(idx);
          swio_listen(link_gpio_num(idx), 15);
          link_flash_end(idx);
        }
        break;
      }
      default: break;
    }
  }
}

void app_main(void) {
  esp_err_t ret = nvs_flash_init();
  if (ret == ESP_ERR_NVS_NO_FREE_PAGES || ret == ESP_ERR_NVS_NEW_VERSION_FOUND) {
    ESP_ERROR_CHECK(nvs_flash_erase());
    ret = nvs_flash_init();
  }
  ESP_ERROR_CHECK(ret);

  ESP_LOGI(TAG, "HELLO XAPOH v4");

  cntxt0 = (app_context_t){ .pixels = {0, 0, 5, 100, 0, 0} };
  config_map_init(&cntxt0);

  // Initialize VCC switch GPIO (0 = 5V normal operation)
  gpio_reset_pin(VCC_SWITCH_GPIO);
  gpio_set_direction(VCC_SWITCH_GPIO, GPIO_MODE_OUTPUT);
  gpio_set_level(VCC_SWITCH_GPIO, 0);

  link_init(); // HW UART1 + 3 links parked idle-high

  // RGB strip
  rmt_tx_channel_config_t tx_chan_config = {
    .clk_src = RMT_CLK_SRC_DEFAULT,
    .gpio_num = RMT_LED_STRIP_GPIO_NUM,
    .mem_block_symbols = 64,
    .resolution_hz = RMT_LED_STRIP_RESOLUTION_HZ,
    .trans_queue_depth = 4,
  };
  ESP_ERROR_CHECK(rmt_new_tx_channel(&tx_chan_config, &led_chan));
  led_strip_encoder_config_t encoder_config = { .resolution = RMT_LED_STRIP_RESOLUTION_HZ };
  ESP_ERROR_CHECK(rmt_new_led_strip_encoder(&encoder_config, &led_encoder0));
  ESP_ERROR_CHECK(rmt_enable(led_chan));
  ESP_ERROR_CHECK(rmt_transmit(led_chan, led_encoder0, cntxt0.pixels, sizeof(cntxt0.pixels), &tx_config));
  ESP_ERROR_CHECK(rmt_tx_wait_all_done(led_chan, portMAX_DELAY));

  // Program-mode flash command listener (no-op without a USB host).
  xTaskCreate(flash_cmd_task, "flash_cmd", 4096, NULL, 5, NULL);

  wifi_init_sta(&cntxt0);
  start_webserver();

  while (1) {
    vTaskDelay(10 / portTICK_PERIOD_MS);
  }
}

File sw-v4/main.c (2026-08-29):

// XAPOH port-expander firmware v4 (CH32V003).
//
// Replaces the v3 I2C slave with a one-wire UART receiver on PD1 (the SWIO pin,
// chip pin 18). The ESP32-C6 sends a fixed 5-byte full-state frame; this firmware
// drives 17 panel outputs accordingly. PD1 is flashed via SWIO by the ESP when the
// board is in program mode (3.3 V), and used as USART1 RX in operation (5 V).
//
// Link wire / mode notes:
//   - USART1 RX is remapped to PD1 (AFIO PCFR1 USART1 remap = 01: RX/PD1, TX/PD0).
//   - Only RX is enabled; PD0 is a driven output (no USART TX function used, so
//     remapping TX onto PD0 is safe to repurpose).
//   - Baud 4800 @ 1.5 MHz core. UART bit ~208 us vs SWIO bit ~1 us => the always-on
//     debug tap can never mistake UART traffic for a programming transaction.
//
// RF discipline (chip lives inside sensitive RF): 1.5 MHz / no PLL, sleep in __WFI
// and wake only on RXNE, 2 MHz output slew, drive only pins that actually change.

#include "ch32fun.h"
#include <stdint.h>

// --- wire protocol -----------------------------------------------------------
// Frame = 0xAA | b0 | b1 | b2 | (b0^b1^b2).  Full-state push, idempotent.
//   b0[0..7] -> PD4, PD5, PD6, PD7, PA1, PA2, PD0, PC0
//   b1[0..7] -> PC1, PC2, PC3, PC4, PC5, PC6, PC7, PD2,
//   b2[0]    -> PD3
#define FRAME_SYNC 0xAA
#define BAUD 4800

// 17 active outputs, packed bit i (i=0..16) -> outputs[i].
static const uint8_t outputs[17] = {
  PD4, PD5, PD6, PD7, PA1, PA2, PD0, PC0, // b0[0..7]
  PC1, PC2, PC3, PC4, PC5, PC6, PC7, PD2, // b1[0..7]
  PD3                                     // b2[0]
};

static uint32_t out_shadow; // last applied packed state (bit i = pin state)

// Drive only the pins whose bit changed since last apply (less switching noise).
static void apply_outputs(uint32_t packed) {
  uint32_t diff = packed ^ out_shadow;
  if (!diff) return;
  for (uint8_t i = 0; i < 17; i++) {
    if (diff & (1u << i)) {
      funDigitalWrite(outputs[i], (packed >> i) & 1u);
    }
  }
  out_shadow = packed;
}

// --- frame receiver (RXNE interrupt) -----------------------------------------
static volatile uint32_t rx_pending; // newest decoded packed state
static volatile uint8_t  rx_ready;   // set when a valid frame arrived

void USART1_IRQHandler(void) __attribute__((interrupt));
void USART1_IRQHandler(void) {
  static uint8_t st, b0, b1, b2;
  // Reading STATR then DATAR clears RXNE and any overrun (ORE) condition.
  (void)USART1->STATR;
  uint8_t d = (uint8_t)USART1->DATAR;

  switch (st) {
    case 0: if (d == FRAME_SYNC) st = 1; break;     // resync on 0xAA
    case 1: b0 = d; st = 2; break;
    case 2: b1 = d; st = 3; break;
    case 3: b2 = d; st = 4; break;
    case 4:
      if (d == (uint8_t)(b0 ^ b1 ^ b2)) {
        rx_pending = (uint32_t)(b0) | ((uint32_t)(b1) << 8) | ((uint32_t)(b2) << 16);
        rx_ready = 1;
      }
      st = 0;
      break;
    default: st = 0; break;
  }
}

// --- setup -------------------------------------------------------------------
static void gpio_init(void) {
  funGpioInitAll();

  // 17 panel outputs: push-pull, 2 MHz slew (low EMI), start low.
  for (uint8_t i = 0; i < 17; i++) {
    funPinMode(outputs[i], GPIO_Speed_2MHz | GPIO_CNF_OUT_PP);
    funDigitalWrite(outputs[i], 0);
  }
  out_shadow = 0;

  // PD1 = USART1 RX (link wire): input, pull-up so the idle line reads high.
  funPinMode(PD1, GPIO_CNF_IN_PUPD); funDigitalWrite(PD1, 1);
}

static void usart_rx_init(void) {
  // AFIO clock is already enabled by funGpioInitAll(); add the USART1 clock.
  RCC->APB2PCENR |= RCC_APB2Periph_USART1;

  // USART1 remap = 01 -> RX on PD1, TX on PD0 (TX unused, TE stays off).
  AFIO->PCFR1 = (AFIO->PCFR1 & ~AFIO_PCFR1_USART1_REMAP_1) | AFIO_PCFR1_USART1_REMAP;

  // 8N1, BRR = Fclk/baud (= 312 @ 1.5 MHz/4800 -> 4808 baud, +0.16%).
  USART1->BRR = FUNCONF_SYSTEM_CORE_CLOCK / BAUD;
  USART1->CTLR1 = USART_CTLR1_RE | USART_CTLR1_RXNEIE | USART_CTLR1_UE;

  NVIC_EnableIRQ(USART1_IRQn);
}

int main(void) {
  SystemInit();

  RCC->CFGR0 = RCC_HPRE_DIV16; // HCLK = SYSCLK/16 = 1.5 MHz
  // Clear PLL/HSE but KEEP the HSITRIM field: writing bare RCC_HSION (0x01) zeroes
  // HSITRIM (default 16, ~0.34%/step) -> ~5% HSI detune -> UART framing fails.
  RCC->CTLR &= ~(RCC_PLLON | RCC_HSEON);

  gpio_init();
  usart_rx_init();

  for (;;) {
    __WFI(); // sleep; wake on RXNE interrupt
    if (rx_ready) {
      rx_ready = 0;
      apply_outputs(rx_pending);
    }
  }
}

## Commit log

2024-02-19 XAPOH boards v1
2024-02-19 moved PCB SVGs
2024-02-19 SW v1.0.3
    [f232h-gd32v.cfg]
2024-02-22 добавил инструкцию на генерацию GERBER файлов
2024-02-22 подпись к панелям
2024-02-23 откатил подписи
2024-02-23 пометка про шрифт
2024-02-23 добавил перечень элементов
2024-02-23 добавил картинку индикатора в инструкцию
2024-02-23 переименовал кнопку
2024-02-26 добавил основную плату харона
2024-02-26 добавил описание
2024-02-28 добавил OSHWA сертификат
2024-02-28 малнькая правка текста
2024-02-28 опечатка
2024-05-27 added knob model
    [knob-inner-v1.stl, knob-outer-v1.stl]
2024-06-24 I2C expander code
2024-08-11 colorful LEDs
2025-06-09 P2K style buttons
2025-06-12 LED0 different color per mode
2025-06-12 LED fix
2025-06-16 wifi credantial fix; restore after black sunday
    [sw-panel-v3-main.c]
2026-05-24 initial sketch of 9E XAPOH case
2026-06-01 first print try
2026-06-21 detect 3 i2c addresses via PD0 pin. a=GND, b=float, c=VDD
2026-06-22 ported from observable framework to no-framework
2026-06-22 no-framework Web3 APP
2026-06-23 add 9E table + 3 i2c devices support
2026-07-20 docs(plans): add v4 esp2wch architecture plan
    ESP32-C6 -> CH32V003 single-wire link: SWIO flash + UART-RX runtime on
    shared PD1. Locks v3->v4 deltas, phasing (P0-P5), and decisions A1-A13.
2026-07-20 feat(sw-v4): CH32V003 UART-RX expander firmware
    ch32fun project (1.5 MHz HSI, no PLL). USART1 RX remapped to PD1, 5-byte
    full-state frame (0xAA|b0|b1|b2|csum), 14 GPIO outputs driven on change.
    Low-noise: WFI sleep, 2 MHz slew, diff against shadow. Debug kept enabled
    so the ESP can reflash over SWIO on the same pin.
    [main.c]
2026-07-20 feat(sw-panel-v4): ESP32-C6 v4 app, SWIO programmer, hosted UI
    Fork of sw-panel-v3 with I2C dropped. Adds:
    - swio_programmer component: in-repo RISC-V SWIO bit-bang flasher (halt,
    unlock, erase, program, verify) driving CH32V003 on gpio0/1/2.
    - link.{c,h}: single HW UART1 TX, GPIO-matrix-switched per target, 5-byte
    full-state frame, idle-high between changes; per-flash gpio interlock.
    - embedded CH32 image (expander_image.h) flashed on WebSerial F0/F1/F2/FA.
    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
2026-07-20 feat(web4): standalone WebSerial programmer tool
    Two-tab browser tool (bridge + expanders). Flashes ESP32-C6 via esptool-js
    and triggers CH32 reflash by sending F0/F1/F2/FA over WebSerial; the ESP
    flashes its embedded image via SWIO (no WebUSB WCH-LinkE). esbuild chain in
    bin/build.js emits a self-contained index.html (bundle gitignored).
2026-07-20 assets(3d): v1.0.0 case models + face STEP
    Case frame + TP STL meshes and face-v12.1.0 STEP.
    [face-v12.1.0.step, xapoh-case-TP-v1.0.0.stl, xapoh-case-frame-v1.0.0.stl]
2026-08-09 swio: flash CH32V003 with no external pull-up resistor
    Rewrite the SWIO bit-bang to flash all 3 CH32V003 expanders with no
    external pull-up — only the ESP's internal pull-up + the chip's own
    internal pull-up on PD1. Bench-validated: F0/F1/F2 all succeed
    (erase, program, verify, reboot).
    Key changes to the bit-bang:
    - ReadBit: glitch-based read — D_HI briefly charges the line fast, then
    D_REL releases so the chip drives its response low. The internal ~45k
    pull-up alone is too slow; the glitch replaces a strong external R.
    - Send1Bit/Send0Bit: driven strong-1 highs (matching the WCH-LinkE);
    the earlier weak-1 (D_REL) on writes distorted timing and was unstable.
    - swio_line_reset: 32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
    [sw-panel-v4-main.c, swio_programmer.c]
2026-08-09 feat(web4): responsive layout, flash-button row, dark info panel
    - Apply .content padding/max-width and wrap the title in
    .header/.header-inner so the page has real horizontal padding;
    make #root a flex column pinned to the viewport (height: 100%, not
    min-height) so the console can both grow and shrink with the window.
    - Fix the white-on-white MAC/Flash info panel: switch its inline
    background from #f0f0f0 to #222 with #eee text, matching the dark
    theme.
    - Lay out the four flash buttons (ESP32C6 / D50 / D51 / D52) in a
    single flex row at 25% each (.flash-row).
    - Gate the D5x expander buttons: disabled (opacity .4, dataset.on
    cleared) until "Прошивка завершена.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
2026-08-09 web4: drop MAC/Flash info panel, compact bridge config editor
    - Remove the MAC/Flash info panel from the bridge tab. It was display-only:
    the MAC was extracted from the chip string and shown but never read by
    anything downstream, and the "Flash: Встроенный (игнорируйте предупреждение
    Flash ID)" line was a static hint. The "Мост подключен" line above it
    still confirms the connection.
    - Compact the bridge config editor: collapse the default WiFi JSON to a
    single line and reduce the editor min-height from 100px to 25px (one
    line) so it doesn't reserve unused vertical space.
    - Rebuild docs/index.html and sw-panel-v4/main/pages.h.
2026-08-09 web4: UX overhaul of the bridge flow — beveled buttons, gating, feedback
    Bugs
    - Disable "Активировать XAPOH" on click (aria-disabled + "Подключение…")
    before the async requestPort/esptool.main() so a second click can't
    fire a second OS port picker. Restored on failure.
    - "Прошить ESP32C6" is now one-shot: disables on click, stays disabled
    after completion (the chip is flashed and rebooting; the D5x buttons
    are the active controls). Re-enabled only on config-parse failure.
    - D5x expander buttons disable all three during a send (finally block),
    so a second click can't re-trigger an in-progress SWIO flash.
    - Dispose the term.onData listener on console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
2026-08-09 Add GPIO3 control for external VCC switch during SWIO programming
    - Define GPIO3 as VCC_SWITCH_GPIO for external voltage control
    - Initialize GPIO3 to output mode, default 0 (5V normal operation)
    - Implement voltage switching in flash_one():
    * Set GPIO3=1 for 3.3V programming mode
    * Wait 300ms for voltage stabilization
    * Perform SWIO flash operation
    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
2026-08-29 Enable 3 more expander outputs: PD0, PC1, PC2 (17 total)
    sw-v4/main.c:
    - Move PD0, PC1, PC2 from reserved inputs into the driven outputs
    array, growing the active output count from 14 to 17.
    - b0 grows from 7 to 8 bits (adds PD0), b1 grows from 7 to 8 bits
    (adds PC1, PC2 at the front), and b2 is now used for its 1 real
    bit (PD3) instead of being ignored.
    - Widen out_shadow/rx_pending from uint16_t to uint32_t and update
    the frame decode to pack all 3 bytes (b0 | b1<<8 | b2<<16).
    - Fix apply_outputs()/gpio_init() loop bounds from 14 to 17 so all
    outputs (including PD3) get initialized and driven.
    sw-panel-v4/lib/main.js:
    - sendGpio() now sends 3 bytes per expander (9 total: g0..g8)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
    [main.c]
